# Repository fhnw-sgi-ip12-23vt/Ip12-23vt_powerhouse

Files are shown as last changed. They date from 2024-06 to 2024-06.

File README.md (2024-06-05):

# Powerhouse

## Readme
***
In diesem Readme werden auf alle wichtigen Elemente verwiesen.

## Überblick über das Projekt Powerhouse
***
Alle wichtigen Elemente der Software-Architektur, sowie alle Informationen zu verwendeter Hardware finden Sie in der Dokumentation. Diese ist folgendermassen aufgeteilt:

* [Hardware-Dokumentation](https://github.com/fhnw-sgi-ip12-23vt/Ip12-23vt_powerhouse/blob/f4988460a4c3d4b095565e1390c6c0ab0d1195cb/docu/hardware/Hardware.adoc)

* [Bedienungsanleitung Spiel](https://github.com/fhnw-sgi-ip12-23vt/Ip12-23vt_powerhouse/blob/d943952f26c9792b2c2e0c8939f13d876f54f816/docu/hardware/Bedienungsanleitung%20Spiel.adoc)

* [Softwaredokumentation (SAD)](https://github.com/fhnw-sgi-ip12-23vt/Ip12-23vt_powerhouse/blob/c4615cf55405ba9b3537b55cfcc192cdb2d660c0/docu/software(sad)/arc42-template.adoc)

* [Bedieungsanleitung Software](https://github.com/fhnw-sgi-ip12-23vt/Ip12-23vt_powerhouse/blob/d943952f26c9792b2c2e0c8939f13d876f54f816/docu/software(sad)/Bedienungsanleitung%20Software.adoc)

(überall Link einfügen)

In der **Hardwaredokumentation** sind alle Produkte aufgelistet, die für den Bau des Produktes nötig sind.

1. [Teileliste](https://github.com/fhnw-sgi-ip12-23vt/Ip12-23vt_powerhouse/blob/f4988460a4c3d4b095565e1390c6c0ab0d1195cb/docu/hardware/Hardware.adoc) mit allen Teilen und den Abmessungen
2. [3D-Druck-Dateien](https://github.com/fhnw-sgi-ip12-23vt/Ip12-23vt_powerhouse/blob/d943952f26c9792b2c2e0c8939f13d876f54f816/docu/hardware/3D-Objekte%20Dateien) mit einer Auflistung der Abmessungen 
3. [Kostenübersicht](https://github.com/fhnw-sgi-ip12-23vt/Ip12-23vt_powerhouse/blob/d943952f26c9792b2c2e0c8939f13d876f54f816/docu/hardware/Kosten%C3%BCbersicht.adoc)

#### Datenblätter
Die Datenblätter sind [hier](https://github.com/fhnw-sgi-ip12-23vt/Ip12-23vt_powerhouse/blob/d943952f26c9792b2c2e0c8939f13d876f54f816/docu/hardware/Datenbl%C3%A4tter) zu finden.

## Programmierkonventionen (Coding-Conventions)
***
Folgende Konventionen werden im Projekt Powerhouse eingehalten:
Namenskonventionen: Packagenamen sind immer klein,

* Klassen sind CamelCase, Variablen sind drinkingCamelCase, Konstanten und Enums sind in UPPER_CASE.
* 1 Tabulator/4 Leerschläge Einrückung pro Block.
* Keine Mehrfachdeklarationen pro Zeile.
* Öffnende Klammer auf der vorherigen Zeile, schliessende auf eine neue Zeile.
* Zeilen sind max. 120 Zeichen lang
* Verkettungen sind umgebrochen auf neue Zeilen mit 8 Leerzeichen Einrückung
* Klassengrösse: nicht grösser als 300 Zeilen

 Im Projekt Powerhouse wird eine [Checkstyle](https://checkstyle.sourceforge.io/) Konfiguration verwendet.

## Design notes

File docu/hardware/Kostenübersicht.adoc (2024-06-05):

_Hier stehen die Kostenübersicht._

[cols="1,1,1,1" options="header"]
|===
|Produkt |Beschreibung |Einkaufsort |Kosten in CHF
|Puppenhaus |FLISAT Puppenhaus |Ikea |19.95
|Holz |Sperrholz Pappel 8 mm dick |DO IT + GARDEN Migros |30.05
|Hobbyglas |Hobbyglas Transparent, 100 × 50 cm, 2 mm |Jumbo |11.95
|Kistengriffe |2 Stk. Kistengriff Verzinkt Buntchrom, 100 × 80 × 15 mm |Jumbo |9.60
|Scharniere |2 Stk. Ayce Scharnier Kantig Gelb Verzinkt, 50 × 50 mm |Jumbo |5.40
|Universalschrauben | Universalschraube, 3 × 20 mm |Migros |5.75
|Schrauben | Schrauben M 3 x 16 mm | Migros |1.95
|Schrauben | Schrauben M 4 x 16 mm | Migros |2.25
|Schrauben | Linsenschrauben M 4 x 16 mm | Migros |2.25
|Drucktaster | 20 Stk. Miniatur-Drucktaster | Reichelt | 12.61
|Wiederstand | 30 Stk. Wiederstand, Kohleschicht, 75 Ohm | Reichelt | 0.80
|LED | 20 Stk. LED, 5 mm, bedrahtet, grün, 39000 mcd, 15°| Reichelt | 4.33
|Steckbrückenkabel | 3 x 20 Stk., Stekcbrückenkabel, 50 cm | Reichelt | 19.19
|Bausatz i2C-Output | Bausatz i2C-Output | Horter & Kalb | 20.90
|Raspberry Pi 4 | Raspberry Pi 4 Model B 4 GB | Ali Cengiz | 53.30

|*Total* | | | *200.00*
|===

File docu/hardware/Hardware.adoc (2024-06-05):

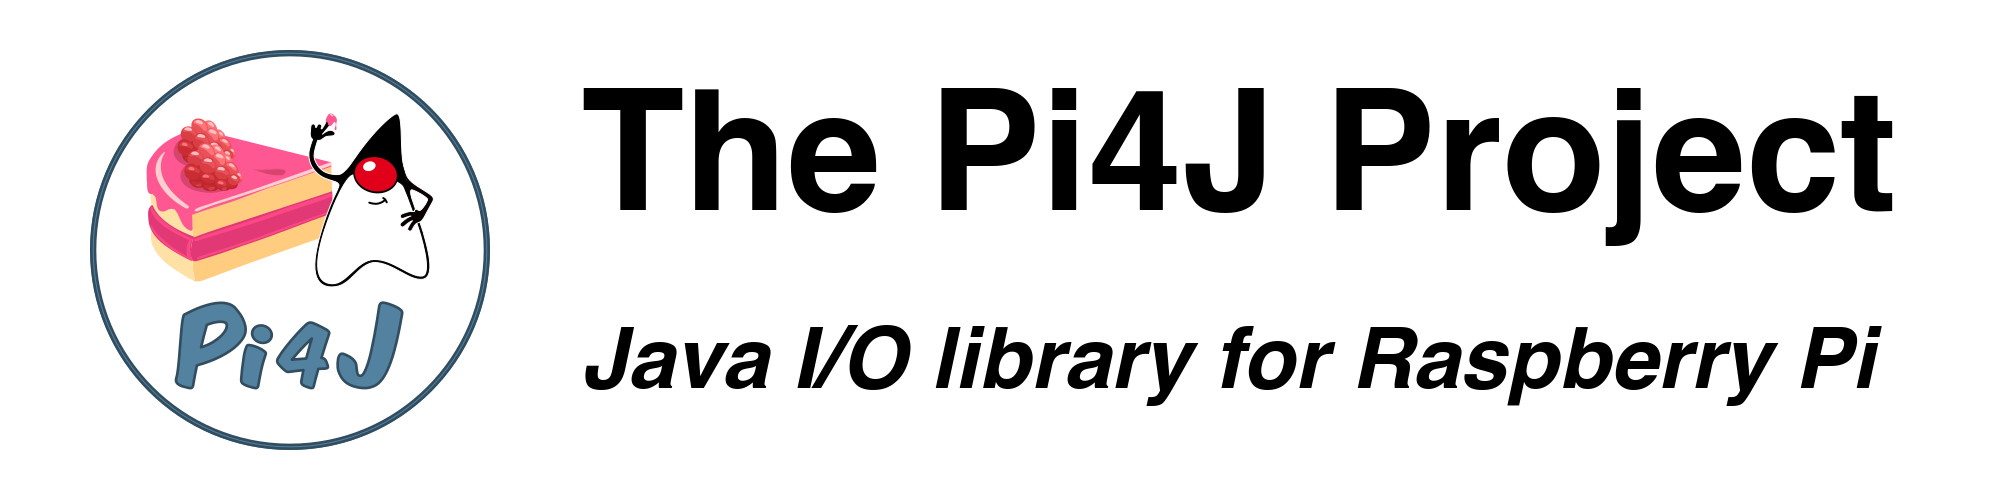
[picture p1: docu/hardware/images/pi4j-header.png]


_Hier stehen die Informationen zur Hardware._

Informationen zum Erstellen und Zusammenbauen finden sie hier: https://www.cs.technik.fhnw.ch/confluence20/display/IP1222vt/Material[]

*Teileliste Elektronik*
[cols="1,1,1,1" options="header"]
|===
|Produkt |Anzahl | Beschreibung |Einkaufsort
|Drucktaster|14 Stk.| Miniatur-Drucktaster|https://www.reichelt.com/ch/de/miniatur-drucktaster-0-5a-24vac-1x-ein-bl-t-250a-bl-p19983.html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[Reichelt]
|Wiederstand | 12 Stk.| Wiederstand | -
|LED | 12 Stk.| LED, 5 mm, bedrahtet, grün, 39000 mcd, 15°| https://www.reichelt.com/ch/de/led-5-mm-bedrahtet-gruen-39000-mcd-15--led-5-39000-gn-p163989.html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[Reichelt]
|Output Module | 2 Stk. | Kit I2C digital output Module| https://www.horter-shop.de/en/i2c-din-rail-modules/117-426-kit-i2c-digital-output-module-4260404260721.html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[Horter & Kalb]

|===
*Teileliste Haus*
[cols="1,1,1,1" options="header"]
|===
|Produkt |Anzahl | Beschreibung |Einkaufsort
|Puppenhaus | 1 Stk. | FLISAT Puppenhaus, wurde auf Ricardo ersteigert für den halben Preis |https://www.ikea.com/ch/en/p/flisat-doll-s-house-wall-shelf-50290785/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[Ikea]
|Holz |1 Stk.| Sperrholz Pappel 8 mm dick |https://www.doitgarden.ch/de/p/640138700000/sperrholz-pappel[DO IT + GARDEN Migros]
|Hobbyglas |1 Stk. | Hobbyglas Transparent, 100 × 50 cm, 2 mm |https://www.jumbo.ch/de/bauen-renovieren/bedachungsmaterialien/kunststoff-wellplatten/hobbyglas-transparent--100--50-cm--2-mm/p/6057452[Jumbo]
|Kistengriffe |2 Stk. | Kistengriff Verzinkt Buntchrom, 100 × 80 × 15 mm |https://www.jumbo.ch/de/maschinen-werkstatt/beschlaege-briefkaesten/beschlaege/ueberfallen-riegel/kistengriff-verzinkt-buntchrom--100--80--15-mm/p/3446281[Jumbo]
|Scharniere |2 Stk. | Scharnier, 100 × 50 mm | Migros
|Universalschrauben | 6 Stk. |  Universalschraube Senkkopf, M 4 × 16 mm, inkl. Mutter | https://www.doitgarden.ch/de/p/601537000000/suki-universalschraube-senkkopf-4x16mm[Migros]
|Universalschrauben | 8 Stk. | Universalschrauben Pan-Head M 4 × 16 mm, inkl. Mutter und Unterlagsscheibe | https://www.doitgarden.ch/de/p/601543200000/suki-universalschraube-pan-head-4x16mm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[Migros]
|Holzschrauben | 30 Stk. | Holzschrauben Linsenkopf verzinkt, 3 × 16 mm | -
|Klettverschluss | 2 Stk. | Klettverschluss selbstklebend, 18.5 x 1 cm| -
|Magnete | 7 Stk. | Magnete ⌀ 1 cm | -
|Blechscheiben | 7 Stk.| Blechscheiben ⌀ 2 cm | -

|===

*Abmessungen Holz für Schaltpult*
[cols="1,1,1" options="header"]
|===
|Teil |Länge |Breite
|Front für Knöpfe |58 cm |16 cm
|Front |58 cm | 4 cm
|Seite 2 Mal mit Abschrägung |44.4 cm |16 cm
|Deckel |58 cm |35 cm
|Boden |58 cm |46 cm
|Rückwand |58 cm |16 cm
|===
image::Schaltpult 1.png[]
image::Schaltpult 2.png[]
image::Schaltpult 3.png[]
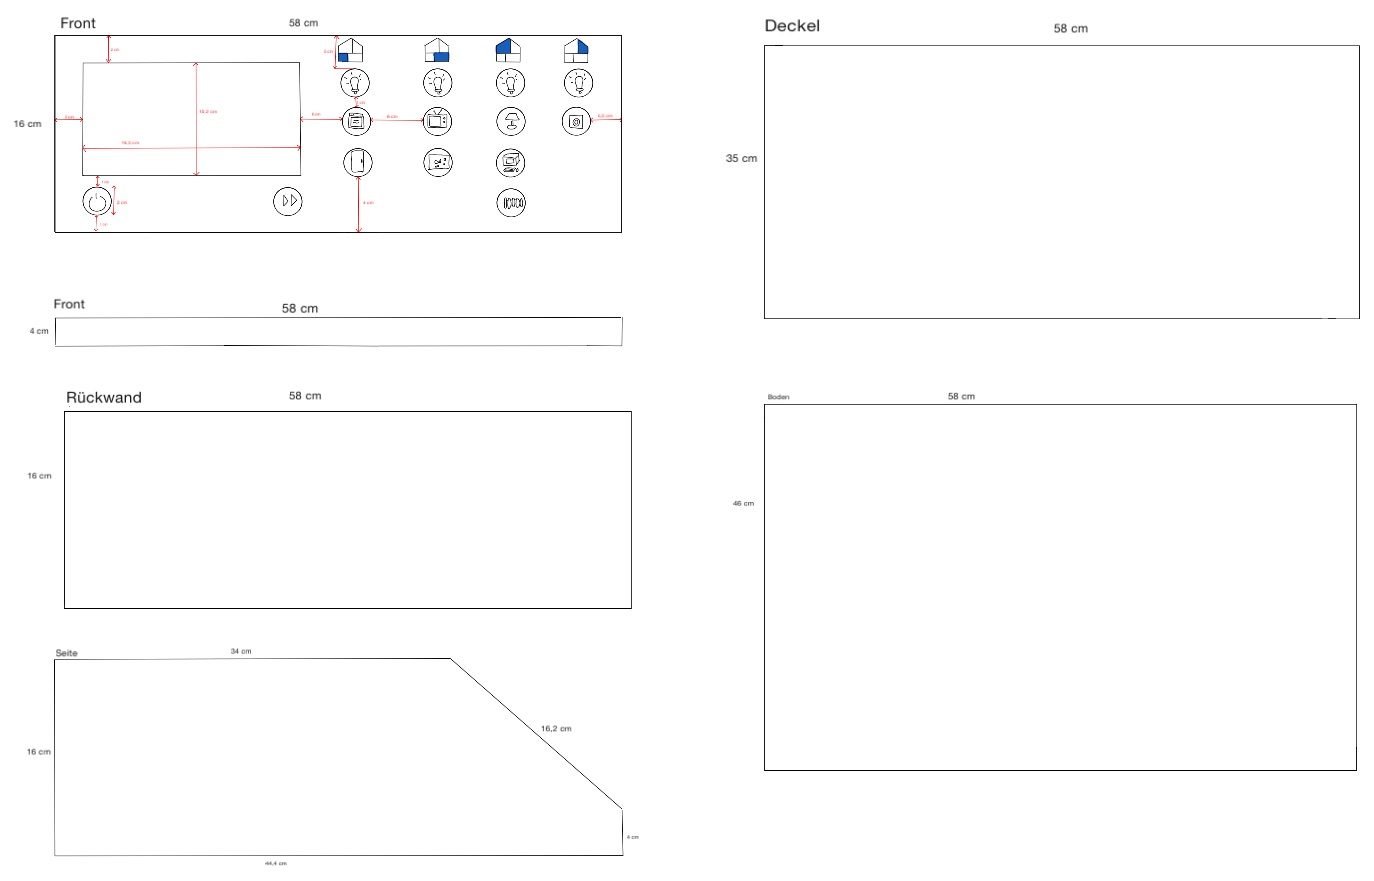
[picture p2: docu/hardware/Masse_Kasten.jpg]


*Abmessungen Plexiglas*
[cols="1,1,1,1" options="header"]
|===
|Produkt |Höhe |Breite |Tiefe
|Front | 50 cm| 58 cm| 0.2 cm
|Aquarium Glas gross  |7 cm |2.5 cm |0.2 cm
|Aquarium Glas klein 2x  |2.5 cm |2.5 cm |0.2 cm
|Dusche | 10 cm |5 cm| 0.2 cm
|Dusche | 10 cm |2.5 cm| 0.2 cm
|Abdeckung Bildschirm | 18.5 cm | 13.5 cm | 0.2 cm
|===

*Abmessungen 3D-Druck Küche*
[cols="1,1,1,1,1" options="header"]
|===
|Produkt |Höhe z |Breite x|Tiefe y|Farbe
|Lampe|15,51 mm | 33,82 mm| 33,82 mm| a
|Herd/Backofen |51,76 mm |45 mm| 29,5 mm| transparent
|Kühlschrank|102,12 | 45 mm |39,02 mm| transparent
|Essisch|44,99 mm | 90 mm| 50,47 mm| weiss
|2x Stühle|69,86 mm |34 mm| 37,57 mm| weiss
|Küchenschrank|48 mm | 45 mm| 20 mm| weiss
|Küchenschranktüre| 44,67 mm | 36,66mm| 4 mm| weiss
|Waschbecken|51,76 mm  |40,69 mm |29,71 mm | weiss
|Dunstabzugshaube| 54 mm| 45 mm| 39,54 mm| schwarz
|===

*Abmessungen 3D-Druck Wohnzimmer*
[cols="1,1,1,1,1" options="header"]
|===
|Produkt |Höhe z |Breite x|Tiefe y|Farbe
|Lampe|15,51 mm | 33,82 mm| 33,82 mm| schwarz
|Fernseher|29,63 mm | 37 mm| 39,21 mm| transparent
|Aquarium Tisch| 27,84 mm| 75 mm| 27,84 mm| schwarz
|Aquarium Deckel| 3,8 mm| 75 mm| 27,84 mm| schwarz
|Aquarium Rahmen| 26,05 mm| 75 mm| 27,84 mm| schwarz
|Musikanlage|15,32 mm | 45 mm| 30,84 mm| transparent
|Sofa|45,6 mm | 90 mm| 61 mm| blau
|Fernsehtisch |33 mm | 75 mm| 40 mm| weisse Oberfläche, schwarze Beine
|Spielkonsole| 27,5 mm | 22,5 mm | 23,75 mm| aussen weiss, innen schwarz
|2x Vase| 20 mm | 12,48 mm | 12,48 mm| weiss
|===

*Abmessungen 3D-Druck Schlafzimmer*
[cols="1,1,1,1,1" options="header"]
|===
|Produkt |Höhe |Breite |Tiefe|Farbe
|Lampe|15,51 mm | 33,82 mm| 33,82 mm| transparent
|Computer|40,83 mm | 38 mm| 31 mm| transparent
|Heizung|49 mm | 11,2 mm| 70 mm| transparent
|Nachttisch|33 mm |40 mm| 30 mm| weinrot/braun
|Bürotisch|61,1 mm |90 mm |53,73 mm| weiss
|Bürostuhl|111,82 mm |50 mm| 48,89 mm| blau
|Nachttischlampe|46,77 mm | 30 mm| 30 mm| transparent
|Bett | 60 mm| 70 mm| 120 mm | weiss
|Kleiderschrank | 135 mm | 35 mm | 75 mm | weinrot/braun
|Bücherregal | 136,08 mm | 35 mm | 19,84 mm | weinrot/braun
|===

*Abmessungen 3D-Druck Badezimmer*
[cols="1,1,1,1,1" options="header"]
|===
|Produkt |Höhe |Breite |Tiefe|Farbe
|Lampe|15,51 mm | 33,82 mm| 33,82 mm| a
|Waschmaschine/Tumbler|48,91 mm | 45 mm| 50,66 mm| transparent
|WC| 61,92 mm| 45 mm| 27,13 mm| weiss
|Waschbecken|71,13 mm |45 mm| 30,06 mm| weiss
|Duschkopf |7,69 mm |9,62 mm| 20 mm| weiss
|===

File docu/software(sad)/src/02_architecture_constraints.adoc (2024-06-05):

[[section-architecture-constraints]]
== Randbedingungen

[role="arc42help"]
****
.Inhalt
Randbedingungen und Vorgaben, die ihre Freiheiten bezüglich Entwurf, Implementierung oder Ihres Entwicklungsprozesses einschränken.
Diese Randbedingungen gelten manchmal organisations- oder firmenweit über die Grenzen einzelner Systeme hinweg.

.Motivation
Für eine tragfähige Architektur sollten Sie genau wissen, wo Ihre Freiheitsgrade bezüglich der Entwurfsentscheidungen liegen und wo Sie Randbedingungen beachten müssen.
Sie können Randbedingungen vielleicht noch verhandeln, zunächst sind sie aber da.

.Form
Einfache Tabellen der Randbedingungen mit Erläuterungen.
Bei Bedarf unterscheiden Sie technische, organisatorische und politische Randbedingungen oder übergreifende Konventionen (beispielsweise Programmier- oder Versionierungsrichtlinien, Dokumentations- oder Namenskonvention).

.Weiterführende Informationen

Siehe https://docs.arc42.org/section-2/[Randbedingungen] in der online-Dokumentation (auf Englisch!).

****

=== Technische Randbedingungen

[cols="3,3" options="header"]
|===
|Randbedingung |Erläuterung
| Hardware | Das System soll auf einem Raspberry Pi 4 laufen.
| Implementierung in Java |Im Rahmen der Projektschiene wird Java verwendet.
|===

=== Organisatorische Randbedingungen

[cols="3,5" options="header"]
|===
|Randbedingung |Erläuterung
| Team | Unser Projektteam, unterstützt durch Teamcoach.
| Budget | Das Budget für das Projekt beträgt 200 CHF.
| Zeitplan | Beginn des Projektes August 2023, Ende im August 2024, Zeitbudget: 180 Stunden pro Person pro Semester.
| Vorgehensmodell | Im Projekt wird mit dem RUP Modell gearbeitet.
| Versionsverwaltung | Versionsverwaltung mit Git auf Gitlab.
|===

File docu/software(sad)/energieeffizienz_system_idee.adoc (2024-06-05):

= Systemidee
Gruppe 2: Energieeffizienz
:toc:

== Kernaufgabe des Systems
Die Kernaufgabe des Systems ist die Darstellung von Energieeffizienz im Alltag. Das System ist verantwortlich für ein flüssiges und stabiles Spielerlebnis.

Wichtige Begriffe beziehen sich auf das Projekt, was muss jemand wissen um das Projekt zu verstehen.

- *Energieeffizienz*: Im System bezieht sich Energieeffizienz auf das Sparen von Energie

== Kategorie von System
Das System ist ein eingebettetes System mit Echtzeitanforderungen. Das System arbeitet eng mit einem Raspberry Pi zusammen. Die Echtzeitanforderungen beziehen sich auf eine schnelle Aufnahme von User Inputs.

== Wesentliche Qualitätsanforderungen
* *Änderbarkeit*:
** Das Spiel soll über eine Datei konfigurierbar sein, damit es schnell angepasst werden kann
* *Effizienz*:
** Das Spiel soll eine schnelle Antwortzeit haben
* *Übertragbarkeit*:
** Das Spiel soll ohne Internet verwendbar sein
** Das Spiel soll gut transportierbar sein
** Das System soll mit einem Autostart ausgestattet sein
* *Zuverlässigkeit*:
** Das Spiel wird von bis zu 20'000 Besucher*innen benutzt
* *Funktionalität*:
** Erfüllen der festgelegten Features
* *Benutzbarkeit*:
** Das Spiel soll selbsterklärend oder in 30 Sekunden erklärbar sein
** Das Spiel soll für Jugendliche ansprechend gestaltet sein

== Relevante Stakeholder
- Primeo Energie: Betreiber und Administrator des Systems
- FHNW
- Yves Simmen: Auftraggeber
- Fachcoaches
- Projekt Team
- Benutzer*innen: Besucher des Energiekosmoses
- Lehrpersonen

== Schnittstellen zu externen Systemen
- Keine

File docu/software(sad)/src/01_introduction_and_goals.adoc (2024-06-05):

[[section-introduction-and-goals]]
==	Einführung und Ziele

[role="arc42help"]
****
Beschreibt die wesentlichen Anforderungen und treibenden Kräfte, die bei der Umsetzung der Softwarearchitektur und Entwicklung des Systems berücksichtigt werden müssen.

Dazu gehören:

* zugrunde liegende Geschäftsziele,
* wesentliche Aufgabenstellungen,
* wesentliche funktionale Anforderungen,
* Qualitätsziele für die Architektur und
* relevante Stakeholder und deren Erwartungshaltung.
****

=== Aufgabenstellung

[role="arc42help"]
****
.Inhalt
Kurzbeschreibung der fachlichen Aufgabenstellung, treibenden Kräfte, Extrakt (oder Abstract) der Anforderungen.
Verweis auf (hoffentlich vorliegende) Anforderungsdokumente (mit Versionsbezeichnungen und Ablageorten).

.Motivation
Aus Sicht der späteren Nutzung ist die Unterstützung einer fachlichen Aufgabe oder Verbesserung der Qualität der eigentliche Beweggrund, ein neues System zu schaffen oder ein bestehendes zu modifizieren.

.Form
Kurze textuelle Beschreibung, eventuell in tabellarischer Use-Case Form.
Sofern vorhanden, sollte die Aufgabenstellung Verweise auf die entsprechenden Anforderungsdokumente enthalten.

Halten Sie diese Auszüge so knapp wie möglich und wägen Sie Lesbarkeit und Redundanzfreiheit gegeneinander ab.

.Weiterführende Informationen

Siehe https://docs.arc42.org/section-1/[Anforderungen und Ziele] in der online-Dokumentation (auf Englisch!).

****

===== Was ist Powerhouse?

* Powerhouse ist ein Puzzle Spiel.
* Das Ziel ist es Jugendlichen das Thema Energieeffizienz näherzubringen.
* Die Spieler*innen müssen in einem Puppenhaus Energie sparen.

===== Wichtige Features:

* Spieler interagieren mit dem Puppenhaus und steuern verschiedene Alltagsgegenstände.
* Der Energieverbrauch von Alltagsgegenständen wird realistisch simuliert.

=== Qualitätsziele

[role="arc42help"]
****
.Inhalt
Die Top-3 bis Top-5 der Qualitätsanforderungen für die Architektur, deren Erfüllung oder Einhaltung den maßgeblichen Stakeholdern besonders wichtig sind.
Gemeint sind hier wirklich Qualitätsziele, die nicht unbedingt mit den Zielen des Projekts übereinstimmen. 
Beachten Sie den Unterschied.

Hier ein Überblick möglicher Themen (basierend auf dem ISO 25010 Standard):

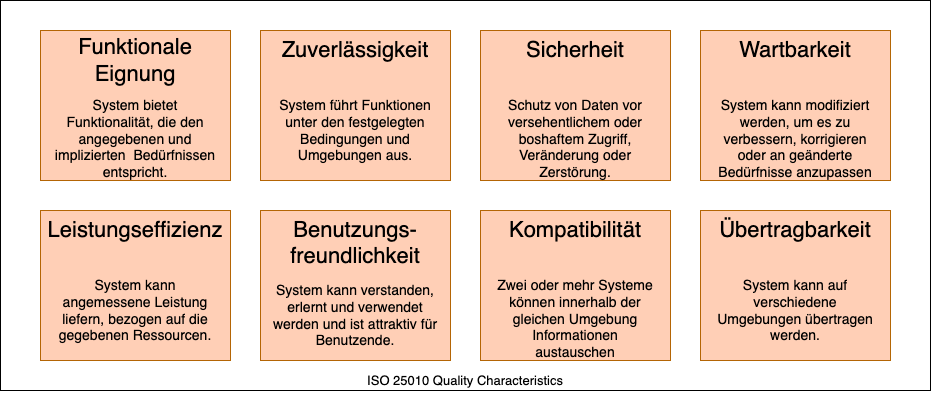
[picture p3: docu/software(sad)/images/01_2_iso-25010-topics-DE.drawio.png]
Kategorien von Qualitätsanforderungen


.Motivation
Weil Qualitätsziele grundlegende Architekturentscheidungen oft maßgeblich beeinflussen, sollten Sie die für Ihre Stakeholder relevanten Qualitätsziele kennen, möglichst konkret und operationalisierbar.

.Form
Tabellarische Darstellung der Qualitätsziele mit möglichst konkreten Szenarien, geordnet nach Prioritäten.
****

Die folgende Tabelle zeigt die wichtigsten Qualitätsziele.
[cols="1,1" options="header"]
|===
|Kategorie |Beschreibung
| Effizienz | Das Spiel soll eine schnelle Antwortzeit haben
| Zuverlässigkeit |Das Spiel wird von bis zu 20'000 Besucher*innen benutzt
| Änderbarkeit | Das Spiel soll über eine Datei konfigurierbar sein, damit es schnell angepasst werden kann
|===

=== Stakeholder

[role="arc42help"]
****
.Inhalt
Expliziter Überblick über die Stakeholder des Systems – über alle Personen, Rollen oder Organisationen –, die

* die Architektur kennen sollten oder
* von der Architektur überzeugt werden müssen,
* mit der Architektur oder dem Code arbeiten (z.B. Schnittstellen nutzen),
* die Dokumentation der Architektur für ihre eigene Arbeit benötigen,
* Entscheidungen über das System und dessen Entwicklung treffen.

.Motivation
Sie sollten die Projektbeteiligten und -betroffenen kennen, sonst erleben Sie später im Entwicklungsprozess Überraschungen.
Diese Stakeholder bestimmen unter anderem Umfang und Detaillierungsgrad der von Ihnen zu leistenden Arbeit und Ergebnisse.

.Form
Tabelle mit Rollen- oder Personennamen, sowie deren Erwartungshaltung bezüglich der Architektur und deren Dokumentation.
****

In Folgendem werden die Stakeholder und ihre Erwartungen beschrieben.
[cols="1,1,2" options="header"]
|===
|Rolle |Kontakt |Erwartungshaltung
| Betreiber und Administrator des Systems | Primeo Energie | Lehrreiches Spiel über Energiesparen für Jugendliche
| Auftraggeber | Yves Simmen | Gute, konstruktive Zusammenarbeit
| Benutzer*innen | Besucher des Energieskosmoses | Flüssiges und unterhaltsames Spielerlebnis
| Projekt Team | Projekt Team | Effizientes Ressourcenmanagement
| FHNW | Louis Paul Wicki | Studierende können ihr Wissen praktisch anwenden
|===

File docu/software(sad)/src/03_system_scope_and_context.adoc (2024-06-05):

[[section-system-scope-and-context]]
== Kontextabgrenzung

[role="arc42help"]
****
.Inhalt
Die Kontextabgrenzung grenzt das System gegen alle Kommunikationspartner (Nachbarsysteme und Benutzerrollen) ab.
Sie legt damit die externen Schnittstellen fest und zeigt damit auch die Verantwortlichkeit (scope) Ihres Systems: Welche Verantwortung trägt das System und welche Verantwortung übernehmen die Nachbarsysteme?

Differenzieren Sie fachlichen (Ein- und Ausgaben) und technischen Kontext (Kanäle, Protokolle, Hardware), falls nötig.

.Motivation
Die fachlichen und technischen Schnittstellen zur Kommunikation gehören zu den kritischsten Aspekten eines Systems.
Stellen Sie sicher, dass Sie diese komplett verstanden haben.

.Form
Verschiedene Optionen:

* Diverse Kontextdiagramme
* Listen von Kommunikationsbeziehungen mit deren Schnittstellen

.Weiterführende Informationen

Siehe https://docs.arc42.org/section-3/[Kontextabgrenzung] in der online-Dokumentation (auf Englisch!).

****

=== Fachlicher Kontext

[role="arc42help"]
****
.Inhalt
Festlegung *aller* Kommunikationsbeziehungen (Nutzer, IT-Systeme, ...) mit Erklärung der fachlichen Ein- und Ausgabedaten oder Schnittstellen.
Zusätzlich (bei Bedarf) fachliche Datenformate oder Protokolle der Kommunikation mit den Nachbarsystemen.

.Motivation
Alle Beteiligten müssen verstehen, welche fachlichen Informationen mit der Umwelt ausgetauscht werden.

.Form
Alle Diagrammarten, die das System als Blackbox darstellen und die fachlichen Schnittstellen zu den Nachbarsystemen beschreiben.

Alternativ oder ergänzend können Sie eine Tabelle verwenden.
Der Titel gibt den Namen Ihres Systems wieder; die drei Spalten sind: Kommunikationsbeziehung, Eingabe, Ausgabe.
****

**<Diagramm und/oder Tabelle>**

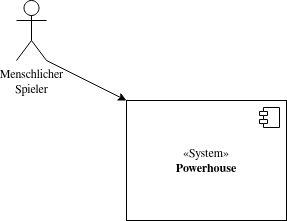
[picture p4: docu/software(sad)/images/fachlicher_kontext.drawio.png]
Bild: Fachlicher Kontext von Powerhouse


**<optional: Erläuterung der externen fachlichen Schnittstellen>**

==== Menschlicher Spieler (Benutzer)

Powerhouse wird von einem Spieler gespielt. Powerhouse leitet den Spieler durch das Spiel. Dabei nimmt das System die Antworten und Entscheidungen des Spielers entgegen.

==== Fremdsysteme

Das System kommuniziert mit keinen Fremdsystemen. (Eventuell Build System?)

=== Technischer Kontext

[role="arc42help"]
****
.Inhalt
Technische Schnittstellen (Kanäle, Übertragungsmedien) zwischen dem System und seiner Umwelt.
Zusätzlich eine Erklärung (_mapping_), welche fachlichen Ein- und Ausgaben über welche technischen Kanäle fließen.

.Motivation
Viele Stakeholder treffen Architekturentscheidungen auf Basis der technischen Schnittstellen des Systems zu seinem Kontext.

Insbesondere bei der Entwicklung von Infrastruktur oder Hardware sind diese technischen Schnittstellen durchaus entscheidend.

.Form
Beispielsweise UML Deployment-Diagramme mit den Kanälen zu Nachbarsystemen, begleitet von einer Tabelle, die Kanäle auf Ein-/Ausgaben abbildet.
****

**<Diagramm oder Tabelle>**

**<optional: Erläuterung der externen technischen Schnittstellen>**

**<Mapping fachliche auf technische Schnittstellen>**

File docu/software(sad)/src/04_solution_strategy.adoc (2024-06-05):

[[section-solution-strategy]]
== Lösungsstrategie

[role="arc42help"]
****
.Inhalt
Kurzer Überblick über die grundlegenden Entscheidungen und Lösungsansätze, die Entwurf und Implementierung des Systems prägen.
Hierzu gehören:

* Technologieentscheidungen
* Entscheidungen über die Top-Level-Zerlegung des Systems, beispielsweise die Verwendung gesamthaft prägender Entwurfs- oder Architekturmuster,
* Entscheidungen zur Erreichung der wichtigsten Qualitätsanforderungen sowie
* relevante organisatorische Entscheidungen, beispielsweise für bestimmte Entwicklungsprozesse oder Delegation bestimmter Aufgaben an andere Stakeholder.

.Motivation
Diese wichtigen Entscheidungen bilden wesentliche „Eckpfeiler“ der Architektur.
Von ihnen hängen viele weitere Entscheidungen oder Implementierungsregeln ab.

.Form
Fassen Sie die zentralen Entwurfsentscheidungen *kurz* zusammen.
Motivieren Sie, ausgehend von Aufgabenstellung, Qualitätszielen und Randbedingungen, was Sie entschieden haben und warum Sie so entschieden haben.
Vermeiden Sie redundante Beschreibungen und verweisen Sie eher auf weitere Ausführungen in Folgeabschnitten.

.Weiterführende Informationen

Siehe https://docs.arc42.org/section-4/[Lösungsstrategie] in der online-Dokumentation (auf Englisch!).

****

[cols="1,1" options="header"]
|===
|Qualitätsziel |Ansätze in der Architektur
| Effizienz | Keine Datenbank, keine Wiederholungen
| Zuverlässigkeit | MVC-Modell
| Änderbarkeit | Konfiguration mittels .ini File

|===

=== Aufbau

Powerhouse ist ein Java-Programm und nach dem MVC-Modell aufgebaut. Es ist unterteilt in:

* Model Klassen -> Speichern Zustände.
* View Klassen -> Darstellung der Zustände, überwacht Zustände von Model Klassen.
* Controller Klassen -> Logik und Kommunikation mit dem Modell.
* Starter Klasse -> Startet das Programm.

Diese Abstrahierung macht das System übersichtlich und erlaubt verschiedene Ansätze für den Input und die Darstellung von Daten.

=== JavaFX
Im System wird JavaFX für alle GUI Elemente verwendet.

JavaFX ist weit verbreitet und ist gut dokumentiert. Zusätzlich ist die Implementierung von verschiedenen Scenes mittels JavaFX sehr nützlich.

=== Keine Datenbank für die Levels
Als Team haben wir uns entschieden keine externe Datenbank für die Aufgaben und Levels zu nutzten.

Gründe:

* Eine Datenbank würde die Performance vom Raspberry Pi einschränken.
* Die Levels kommen immer in der gleichen Reihenfolge und erfordern keine komplexen Abfragen.
* Würde System unnötig komplexer machen.

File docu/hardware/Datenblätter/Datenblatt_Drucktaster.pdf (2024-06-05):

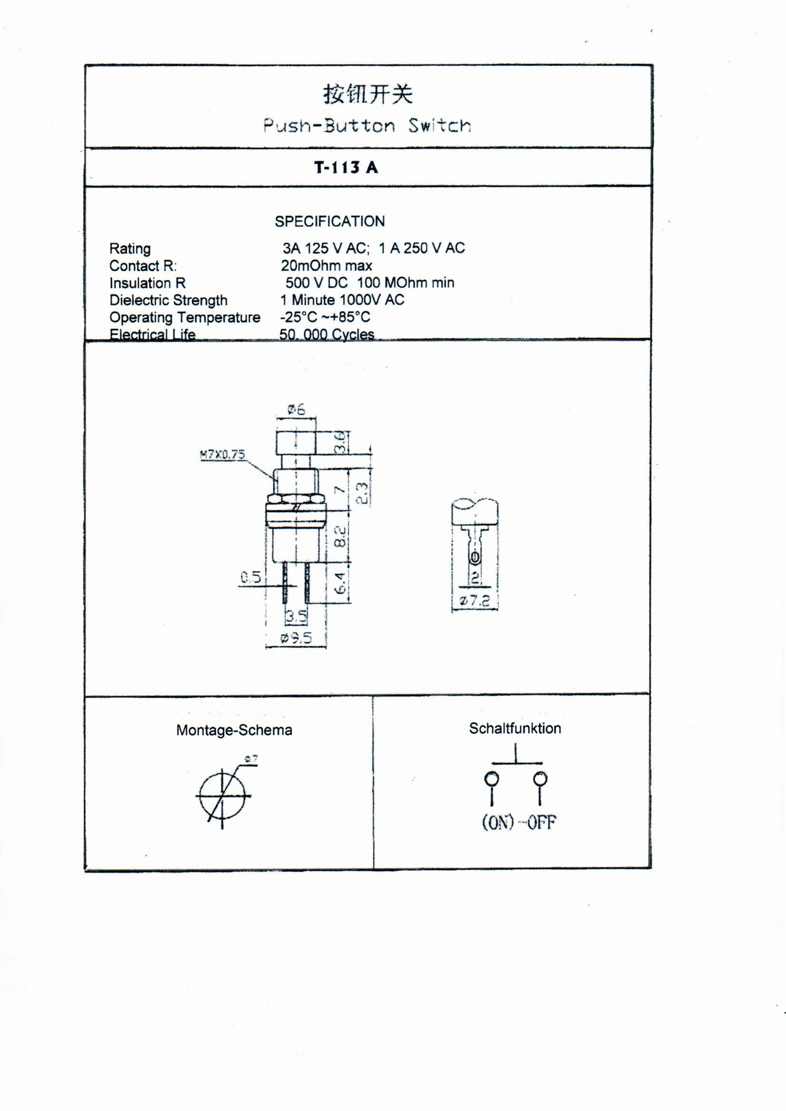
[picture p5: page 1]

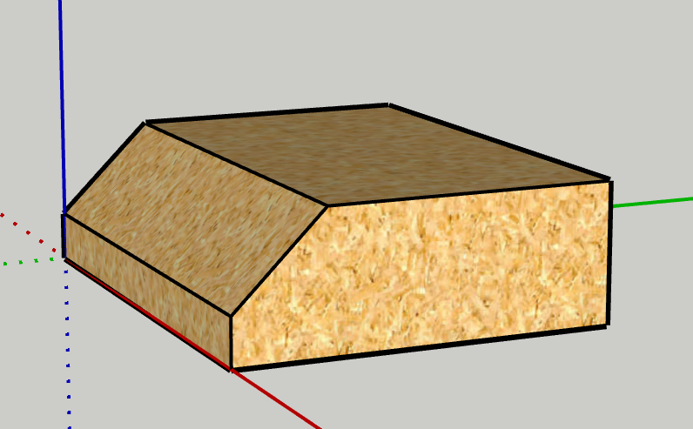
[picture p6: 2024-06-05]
docu/hardware/images/Schaltpult 3.png

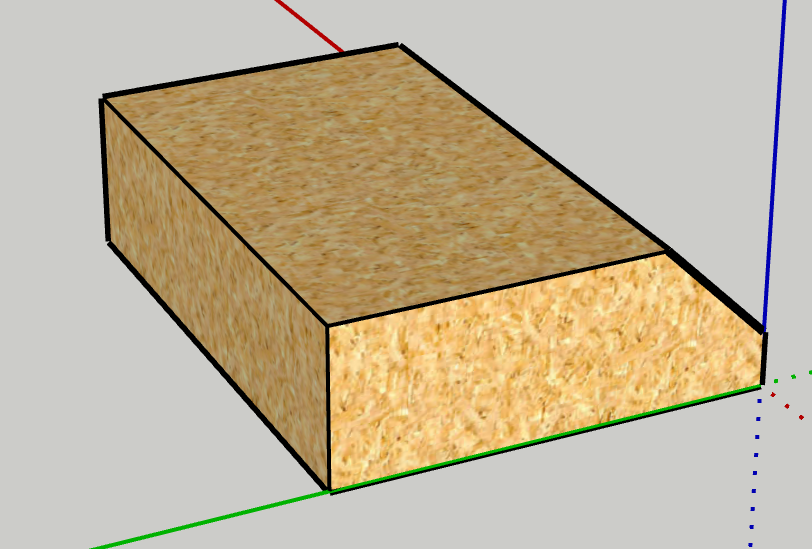
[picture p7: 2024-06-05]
docu/hardware/images/Schaltpult 1.png

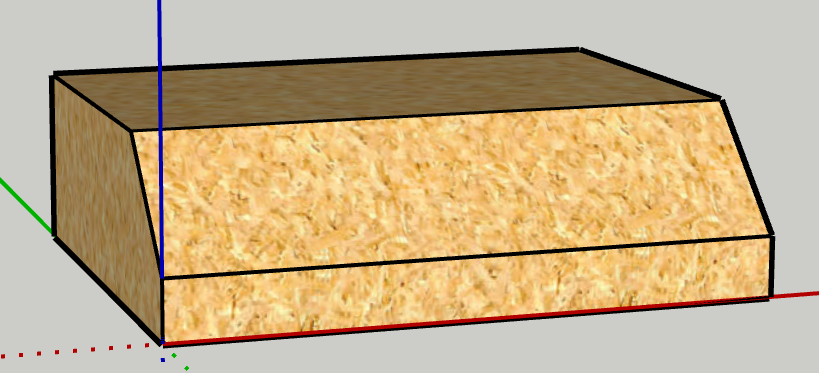
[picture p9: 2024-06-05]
docu/hardware/images/Schaltpult 2.png

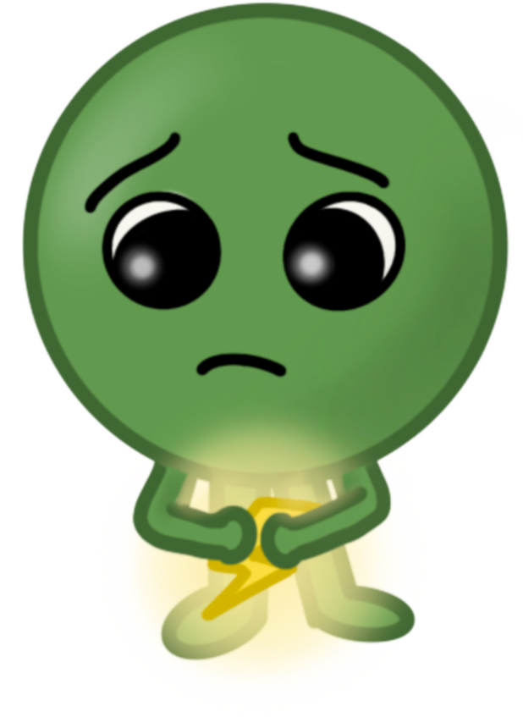
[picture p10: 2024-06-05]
energieeffizienz-sourcecode/src/main/resources/img/Elektronix/Level_8_Spielabbruch.png

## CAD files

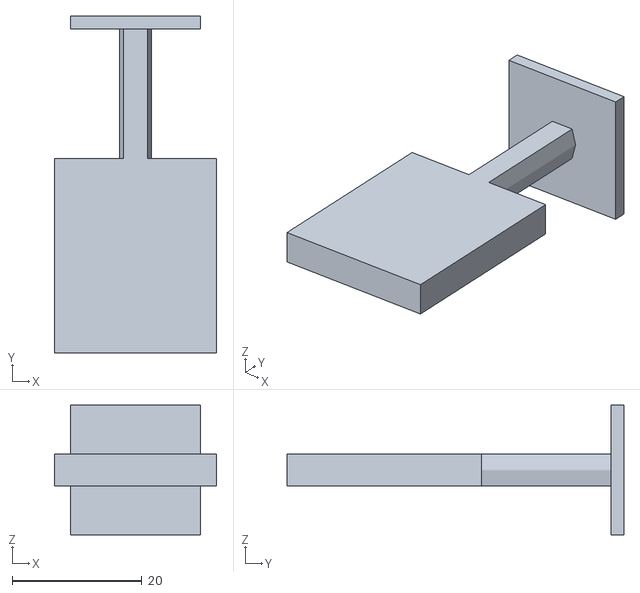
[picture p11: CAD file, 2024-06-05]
docu/hardware/3D-Objekte Dateien/Buttons/Duschkopf.stl
25.0 x 52.0 x 20.0

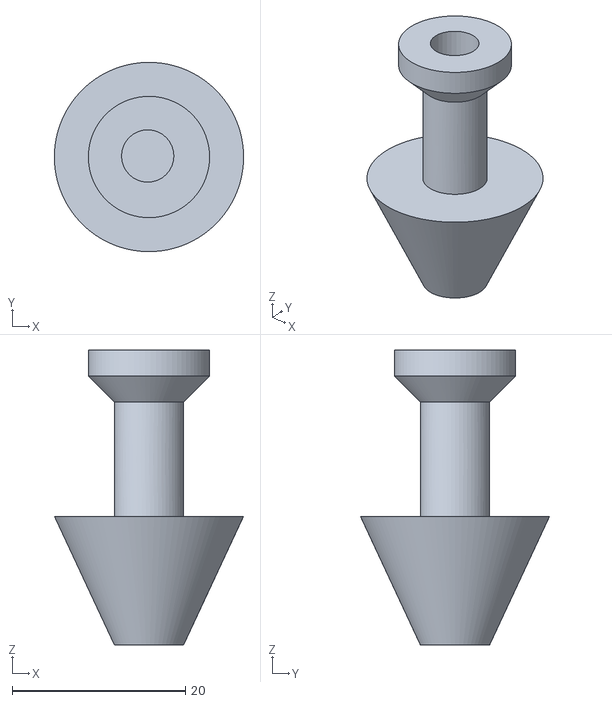
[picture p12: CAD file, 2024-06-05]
docu/hardware/3D-Objekte Dateien/Transparente Objekte/Nachttischlampe.stl
21.8 x 21.8 x 34.1

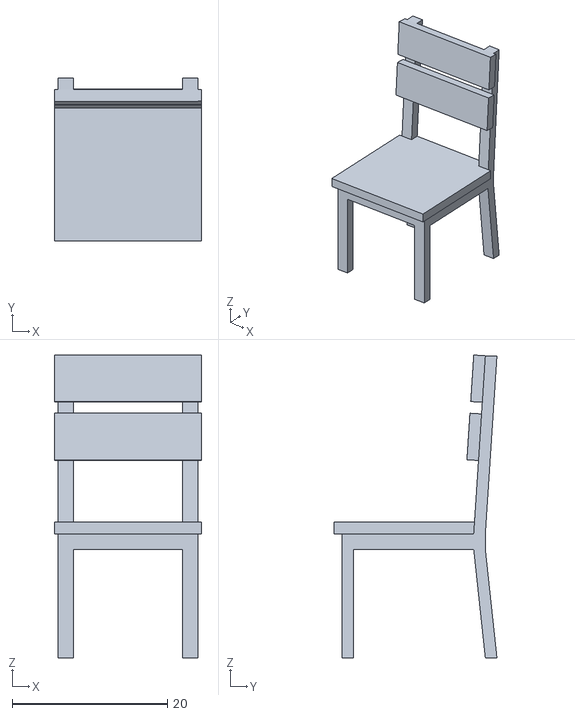
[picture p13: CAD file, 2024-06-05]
docu/hardware/3D-Objekte Dateien/Weitere Objekte/Küche/Küchenstuhl.stl
19.0 x 21.0 x 39.0

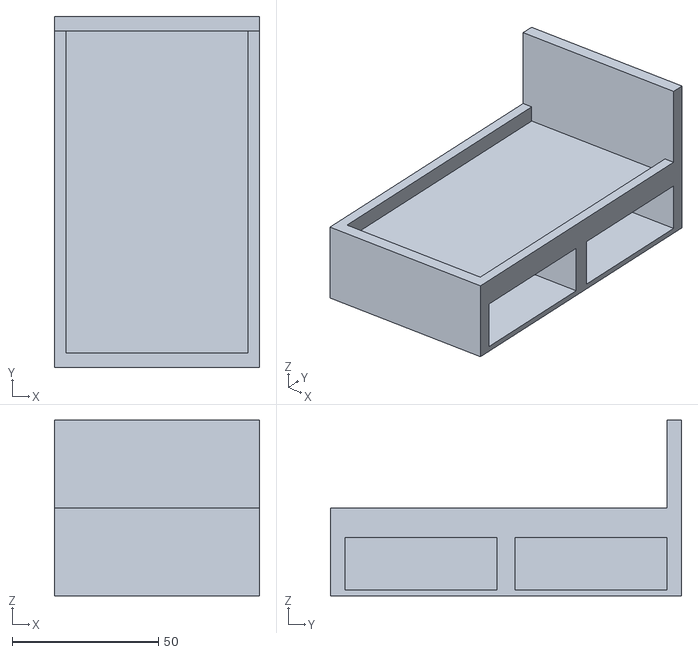
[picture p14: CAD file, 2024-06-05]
docu/hardware/3D-Objekte Dateien/Weitere Objekte/Schlafzimmer/Bett.stl
70.0 x 120.0 x 60.0

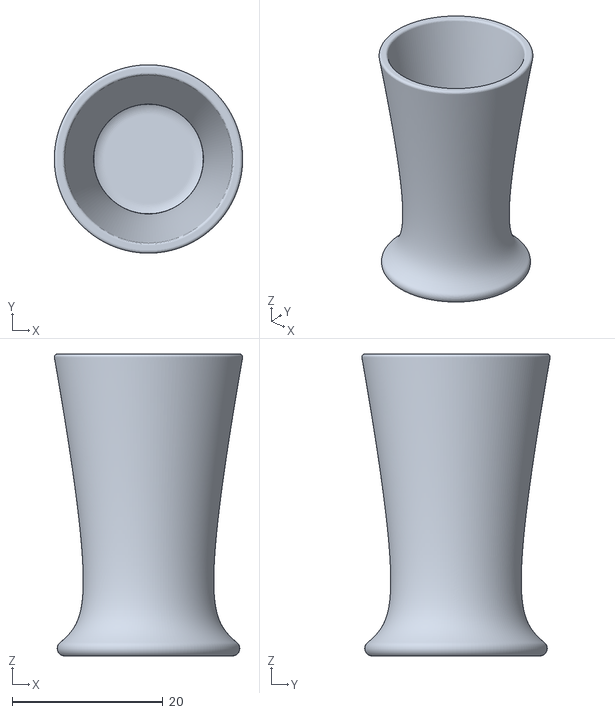
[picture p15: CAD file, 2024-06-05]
docu/hardware/3D-Objekte Dateien/Weitere Objekte/Wohnzimmer/Vase.stl
25.0 x 25.0 x 40.0

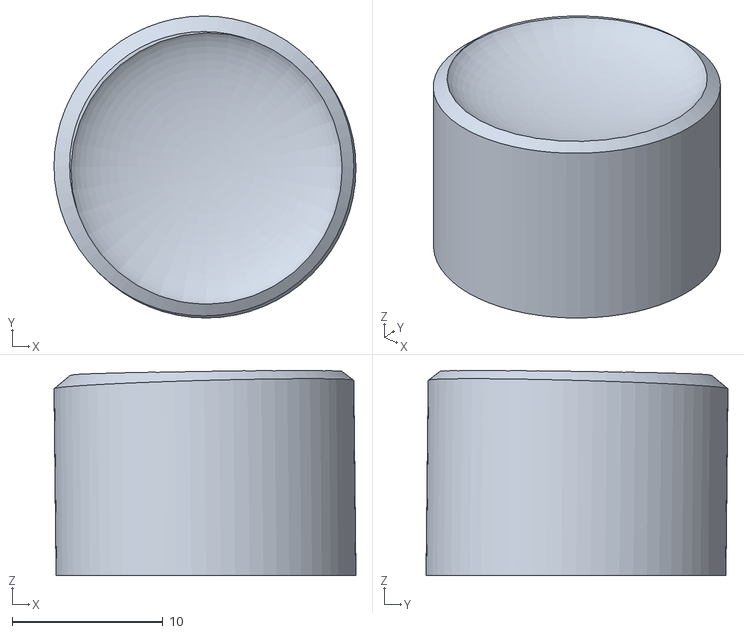
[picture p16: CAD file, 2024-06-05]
docu/hardware/3D-Objekte Dateien/Buttons/Button Blank.stl
20.0 x 20.0 x 13.6

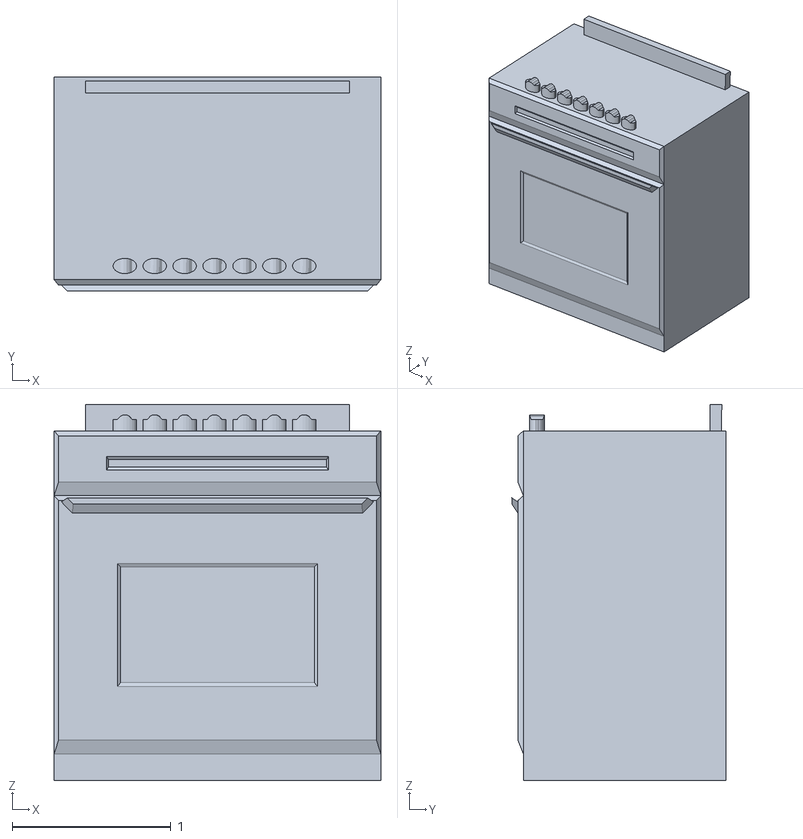
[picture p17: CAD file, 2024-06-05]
docu/hardware/3D-Objekte Dateien/Transparente Objekte/Backofen_Herd.stl
2.06 x 1.35 x 2.37

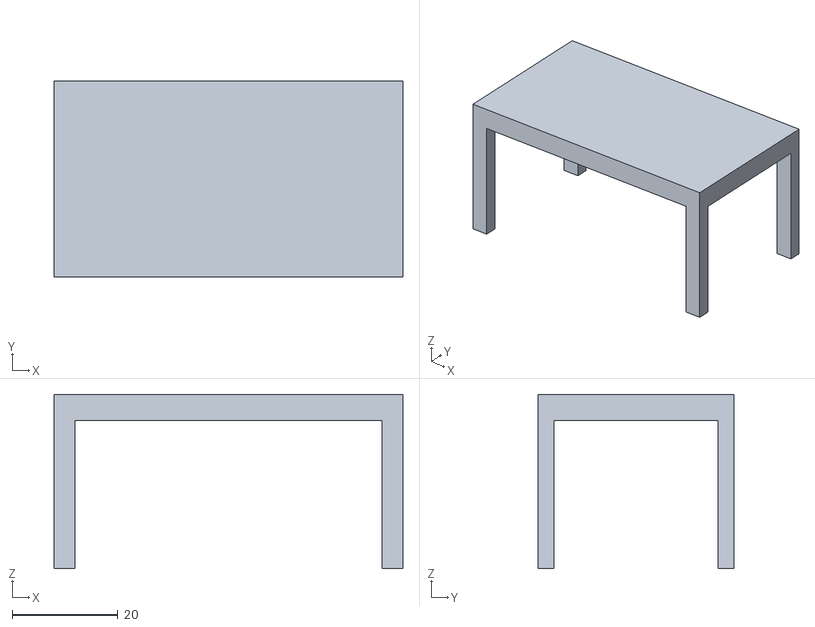
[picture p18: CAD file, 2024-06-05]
docu/hardware/3D-Objekte Dateien/Weitere Objekte/Küche/Esstisch.stl
66.0 x 37.0 x 33.0

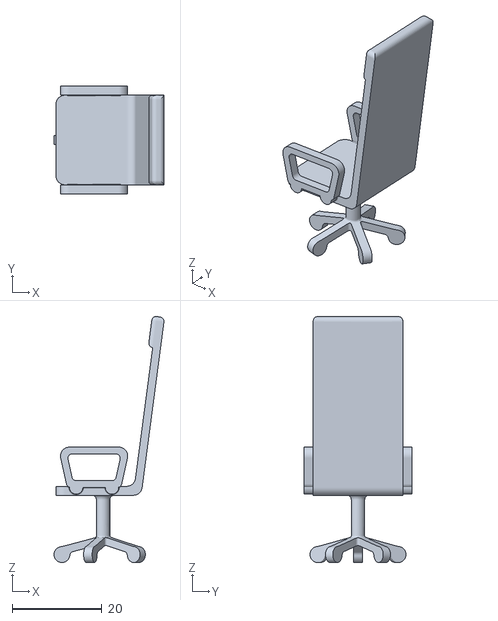
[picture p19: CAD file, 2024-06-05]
docu/hardware/3D-Objekte Dateien/Weitere Objekte/Schlafzimmer/Bürostuhl.stl
24.5 x 24.0 x 54.9

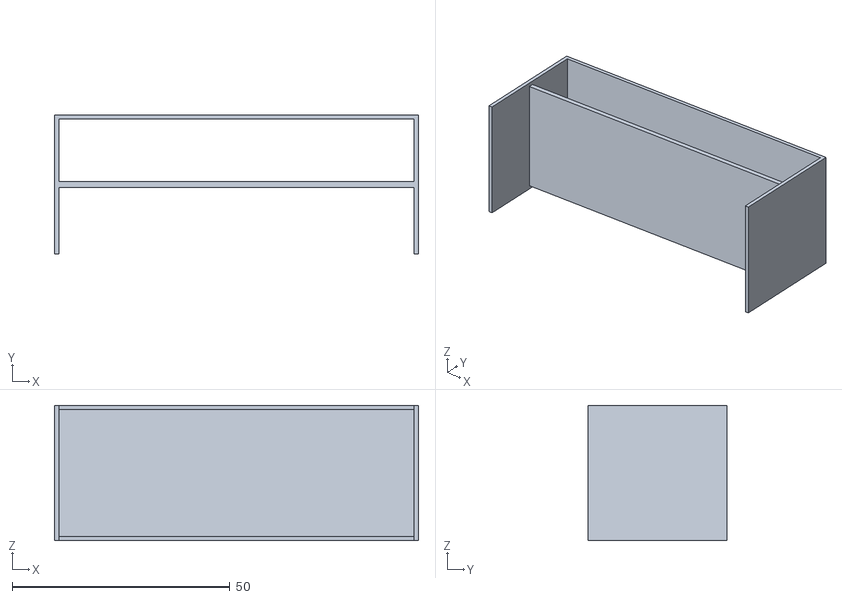
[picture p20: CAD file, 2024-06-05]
docu/hardware/3D-Objekte Dateien/Weitere Objekte/Wohnzimmer/Aquarium_Tisch.stl
83.5 x 32.0 x 31.0

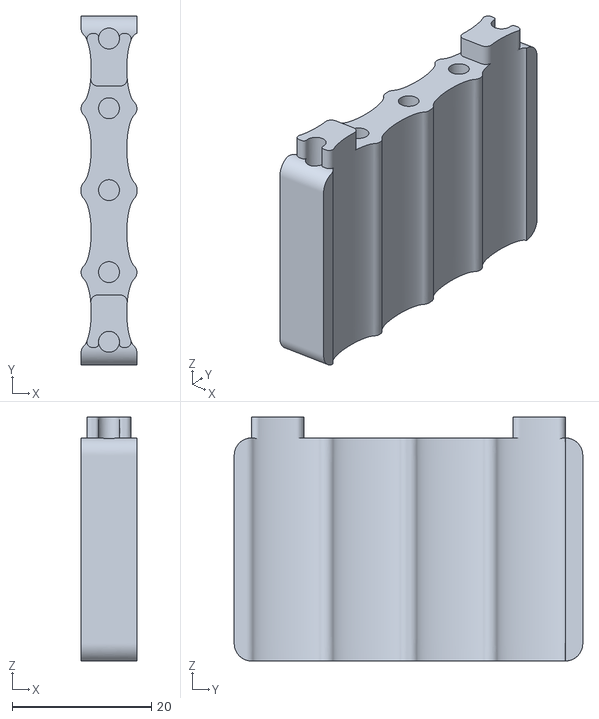
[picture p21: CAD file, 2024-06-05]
docu/hardware/3D-Objekte Dateien/Transparente Objekte/Heizung.stl
8.00 x 50.0 x 35.0

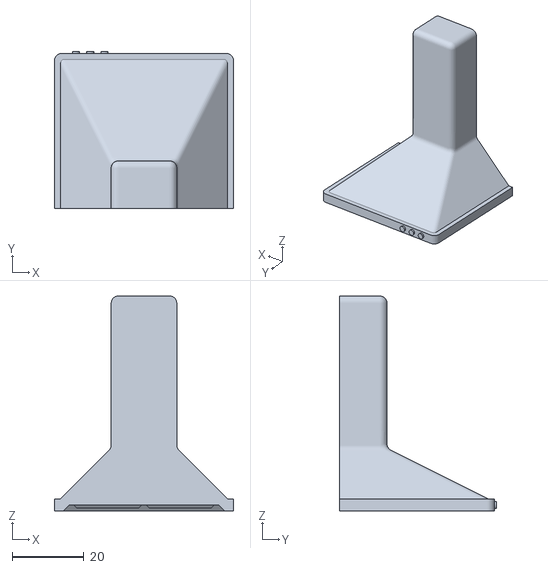
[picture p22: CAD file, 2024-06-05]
docu/hardware/3D-Objekte Dateien/Weitere Objekte/Küche/Verdunstungshaube.stl
50.0 x 43.9 x 60.0

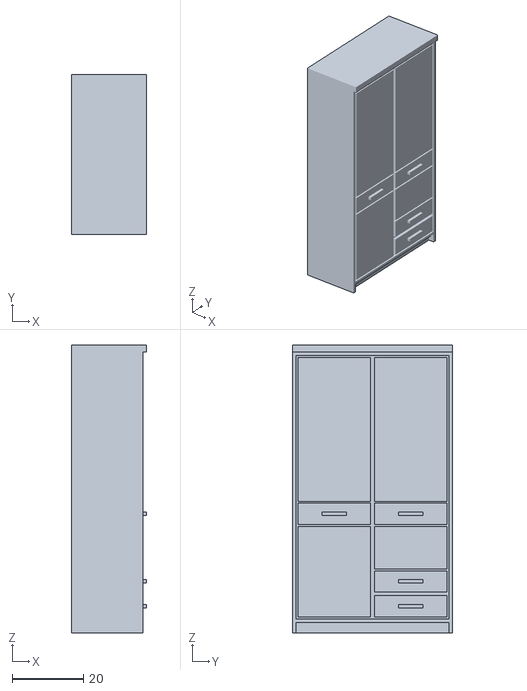
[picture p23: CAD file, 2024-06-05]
docu/hardware/3D-Objekte Dateien/Weitere Objekte/Schlafzimmer/Kleiderschrank.stl
21.0 x 45.0 x 81.0

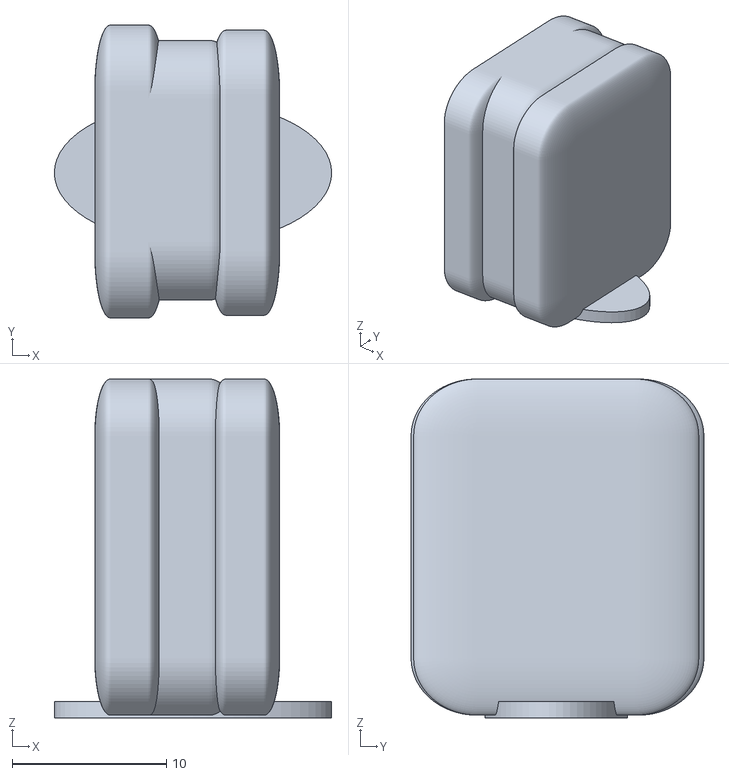
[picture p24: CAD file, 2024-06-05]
docu/hardware/3D-Objekte Dateien/Weitere Objekte/Wohnzimmer/Spielkonsole.stl
18.0 x 19.0 x 22.0

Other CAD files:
docu/hardware/3D-Objekte Dateien/Transparente Objekte/Lampe.stl
docu/hardware/3D-Objekte Dateien/Weitere Objekte/Küche/Küchenschranktüre.stl
docu/hardware/3D-Objekte Dateien/Weitere Objekte/Schlafzimmer/Nachttisch.stl
docu/hardware/3D-Objekte Dateien/Weitere Objekte/Küche/Küche_Waschbecken.stl
docu/hardware/3D-Objekte Dateien/Weitere Objekte/Küche/Küchenschrank.stl
docu/hardware/3D-Objekte Dateien/Weitere Objekte/Schlafzimmer/Bürotisch.stl
docu/hardware/3D-Objekte Dateien/Weitere Objekte/Wohnzimmer/Aquarium_Deckel.stl
docu/hardware/3D-Objekte Dateien/Weitere Objekte/Wohnzimmer/Aquarium_Rahmen.stl
docu/hardware/3D-Objekte Dateien/Weitere Objekte/Wohnzimmer/Bücherregal.stl
docu/hardware/3D-Objekte Dateien/Weitere Objekte/Wohnzimmer/Fernsehtisch.stl
docu/hardware/3D-Objekte Dateien/Weitere Objekte/Wohnzimmer/Sofa.stl

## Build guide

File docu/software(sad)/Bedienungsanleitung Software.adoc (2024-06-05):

= Bedienungsanleitung für die Spielsoftware

== Software (Spiel)

=== Spielübersicht

*Ziel des Spiels*

Unser Produkt ist ein physisches Spiel, welches auf spielerische Art Jugendlichen aufzeigt. Wie der Umgang mit Energiesparen effizient gestaltet werden kann.
Das Spiel findet in einem physischen Puppenhaus statt und handelt um das Energiemonster Elektronix,
welches traurig ist, da dieser keine Energie mehr hat. Der spielenden Person werden verschiedene Aufgaben gestellt,
indem im Haus Alltagsgegenstände ein- oder ausgeschaltet werden müssen. Diese Gegenstände sind jeweils mit LEDs
versehen und werden mithilfe eines Druckknopfes eingeschaltet. Das Ziel ist es, Energie im Haus zu sparen, indem je nach
der Situation, dass Gegenstände ein- und ausgeschaltet werden und Elektronix sich mit dieser Energie aufladen kann und somit zufrieden ist.

*Hauptfeatures*

[cols="1,2,6", options="header"]
|===
| ID
| Name
| Kurzbeschreibung

| F01
| Spielführung (Gameplay)
| Spieler*innen interagieren mit dem Puppenhaus, steuern verschiedene Alltagsgegenstände und erleben ein unterhaltsames sowie lehrreiches Gameplay. Die Spielführung leitet die Nutzer durch Szenarien, in denen sie ihre Entscheidungen bezüglich des Energieverbrauchs treffen.

| F02
| Interaktion UI-Spielmenü (Druckknöpfe, Display)
| Das Display des Spielmenüs bietet eine benutzerfreundliche Oberfläche, über die Spieler*innen das Spiel starten und Informationen über ihre Fortschritte erhalten können. Die intuitive Navigation ermöglicht eine reibungslose Interaktion.

| F03
| Energieverbrauchssimulation von Alltagsgegenständen
| Spieler*innen erleben eine realistische Simulation, bei der sie den Energieverbrauch von Alltagsgegenständen im Puppenhaus steuern. Die Interaktion vermittelt ein Verständnis für die Auswirkungen von Entscheidungen auf den Energieverbrauch.

| F04
| Portability und Usability
| Das Spiel oder Exponat soll leicht transportierbar sein. Die schnelle Auf- und Abbauzeit gewährleistet eine effiziente Nutzung, während die Sicherheit und einfache Handhabung für den Betreiber ein essentielles Bedürfnis ist. Die Selbsterklärung des Spieles und eine schnelle Antwortzeit sind entscheidend, um das Interesse der Schüler*innen im primären Zielpublikum (7. - 9. Schuljahr) zu erhalten.

| F05
| Szenarien mit Entscheidungsmöglichkeiten
| Spieler*innen interagieren mit realistischen Alltagsszenarien im Puppenhaus, treffen Entscheidungen zur Energieeffizienz und erleben unmittelbare Auswirkungen auf den Spielfortschritt. Diese Szenarien fördern ein spielerisches Verständnis für nachhaltige Entscheidungsprozesse.

| F06
| Anzeige von Statistiken und Feedback
| Spieler*innen erhalten Statistik über ihren Energieverbrauch und Feedback zu ihren Entscheidungen. Dies ermöglicht eine selbstreflektierte Analyse und fördert das Verständnis für energieeffizientes Verhalten.

|===

'''

=== Neuinstallation

*Vorbereitung:*
Vor der Neuinstallation sollten alle wichtigen Daten gesichert werden. Es ist empfehlenswert, dass die aktuelle Version des Spiels deinstalliert wird, um mögliche Konflikte mit der neuen Installation zu vermeiden.

==== Setup Raspberry Pi 4

**Raspberry Pi OS Installation**
Zur Neuinstallation eines Raspberry Pis muss zuerst das richtige OS installiert werden. Folgen Sie dazu dem https://www.pi4j.com/getting-started/set-up-a-new-raspberry-pi/[Pi4J Setup Guide].

**Remote-Verbindung zum Raspberry Pi**
Nach der OS Installation muss eine Maus, Tastatur und ein Monitor am RasPi angeschlossen werden. Für die Verbindung mit Ihrem Computer befolgen Sie folgende Schritte:

RasPi mit Strom versorgen. Der RasPi startet automatisch und bootet in das OS.

RaspberryPi mit einem Netzwerk verbinden. (Netzwerkassistent des OS nutzen)

Nach dem erfolgreichen Verbinden mit einem Netzwerk wird die IP-Adresse im Desktop-Hintergrundbild angezeigt.

Nun kann mit der Run Konfiguration "Run on PI(X11)" welche von Maven importiert wird, wenn das POM als Maven Projekt geladen wird, ausgeführt werden.

falls die Verbindung fehlschlägt, überprüfen Sie, ob sich der PC im gleichen LAN wie der Raspberry Pi befindet.

Zur Problemlösung und weiteren Informationen verweisen wir auf:

https://www.pi4j.com/[Pi4J Projekt - Homepage]

https://www.raspberrypi.com/documentation/[Raspberry Pi - Dokumentation]

===== Run on Pi (X11)
Mit dem Ausführen der "Run on Pi(X11)"-Run Konfiguration werden alle für die Applikation benötigten Artifakte auf das RasPi in den "/home/pi/deploy"-Ordner kopiert. Zudem werden Skripts für die Installation des Autostarts der Applikation in diesen Ordner kopiert. All diese Artifakte sind in der "POM.xml"-Datei deklariert.

===== Einrichten des Raspberry Pi
Für das Einrichten des Raspberry Pi’s werden mehrere Skripts benötigt. Diese werden bei jedem Deployment auf den Raspberry Pi kopiert. Diese Skripts sind unter anderem dazu da, die Monitor Einstellungen zu übernehmen und den Autostart des Spiels einzurichten.

Dazu existiert eine Run-Konfiguration "Installscript on Pi" welche die Scripts auf dem Raspberry Pi ausführen und alles einrichten.

'''
=== Spielsteuerung
* Steuerungselemente
* Anpassung der Steuerungseinstellungen

Dieser Abschnitt erläutert die Interaktionsmechanismen und Konfigurationsmöglichkeiten der Spielsteuerung, die darauf ausgelegt sind, eine intuitive und anpassbare Benutzererfahrung zu ermöglichen.

*1. Steuerungselemente:*

Das zentrale Interface für die Spielinteraktion befindet sich auf einem Schaltpult, das alle notwendigen Steuerungselemente umfasst:

*Druckknöpfe:*
Über diese Knöpfe steuern die Spieler*innen die Ein- und Ausschaltung von Genständen im Puppenhaus, was direkte Auswirkungen auf den Energieverbrauch hat.

*Display:*
Das Display am Schaltpult ist zentral für die Interaktion der Spieler mit dem Spiel. Es bietet  Informationen und visuelles Feedback zu den Spielaktionen und -ergebnissen:

* Das Display zeigt Fragen zum Energiesparen und gibt Tipps. Diese können darauf hinweisen, ob eine Aktion richtig oder falsch war, um den Spielern zu helfen, energieeffizientere Entscheidungen zu treffen.

* Die Anzahl der Punkte, die die Spieler basierend auf ihren Aktionen und Entscheidungen im Spiel sammeln, werden deutlich mit einem Barometer dargestellt.

* Die Stimmung des Elektronix, der je nach den Aktionen der Spieler glücklich oder traurig sein kann, wird visuell auf dem Display angezeigt.

*2. Anpassung der Steuerungseinstellungen:*

Dieser Abschnitt erläutert, wie die Steuerungselemente im Code angepasst werden können, falls Anpassungen nötig sind. Das bezieht sich auf die Funktionalitäten der Druckknöpfe und das Display, welche zentral für die Interaktion im Spiel sind.

*Anpassung der Druckknöpfe:* Die Druckknöpfe werden durch die Klasse *SimpleButton* im Paket (com.pi4j.mvc.powerhouse.components) gesteuert. Diese Klasse ist für die Behandlung der Eingaben von Druckknöpfen zuständig und bietet Methoden, um auf verschiedene Zustände der Druckknöpfe zu reagieren. Jede Methode enthält kurze Kommentare, die deren Zweck beschreiben.

*Anpassung des Displays:* Im Projektverzeichnis wird der Ordner *view* gefunden, der in *gui* und *pui* unterteilt ist und beim *resources* wird den *questions.json* gefunden. Diese Bereiche sind für die Steuerung der Logik und des Layouts der Benutzeroberfläche zuständig.

*ioAll.csv:* Dieses CSV befindet sich im Paket (com.pi4j.mvc.powerhouse.components). Hier können die LEDs und Druckknöpfe einander zugeordnet werden. "E + Zahl" sind für die LEDs und "D + Zahl" sind für die Buttons. Die folgende Tabelle kennzeichnet jedem Simulationsgegenstand im Puppenhaus eine PIN-Nummer (Ex oder Dx), welches dem Gegenstand jeweils ein Button und eine LED zuweist. Auf Grund den technischen Gegebenheiten des Raspberry Pi 4 bezüglich GPIO-Pins, ist das Spiel auf zwei zusätzliche I2C Output Extension-Boards angewiesen, dass die entsprechenden LEDs separat anschließt und ansteuert. *Simulations-Gegenstände müssen exakt mit der Bezeichnung im 'questions.json' (Attribute: "activeAtStart" & "Answer") übereinstimmen.*

[cols="2,2,2,1,1" , options="header"]
|===
|Raum im Puppenhaus
|Simulations-Gegenstand
|Device-Adresse des I2C Extension-Board
|LED-PIN
|Button-PIN
.4+|Schlafzimmer| LampeSchlafzimmer      | 32  | E1  | D4
                | NachttischLampe        | 32  | E3  | D6
                | Heizung                | 32  | E4  | D11
                | Computer               | 32  | E6  | D5
.2+|Badezimmer  | LampeBadezimmer        | 32  | E5  | D16
                | Waschmaschine/Tumbler  | 32  | E2  | D17
.3+|Wohnzimmer  | LampeWohnzimmer        | 34  | E6  | D20
                | Fernseher/Spielkonsole | 34  | E3  | D25
                | Aquarium               | 34  | E4  | D23
.3+|Küche       | LampeKueche            | 34  | E1  | D22
                | Herd/Backofen          | 34  | E2  | D21
                | Kuehlschrank           | 34  | E5  | D24
|===

==== questions.jason
Diese JSON-Datei enthält die Definitionen der Fragen und ist zentral für die Anpassung der Spielinhalte. Durch Änderungen an dieser Datei können die Fragen und Antworten, die im Spiel verwendet werden, modifiziert oder erweitert werden. Jede Frage benötigt Folgendes:

* *Difficulty:* Hier wird der Schwierigkeitsgrad einer Frage bestummen. Es gibt:
   - Einstiegslevel: Hier können keine Punkte gewonnen oder verloren werden.
   - Easy: 10 Punkte gewinnen oder 5 Punkte verlieren
   - Medium: 20 Punkte gewinnen oder 10 Punkte verlieren
   - Hard: 30 Punkte gewinnen oder 15 Punkte verlieren

Die Difficulty kann im Enum "Difficulty" im Paket "Game"  angepasst werden.

* *Question:* Hier wird die Aufgabe gestellt.
* *ActiveAtStart:* Hier werden die Gegenstände aufgelistet, die zu Beginn des Levels an sein sollten. (Gegenstände müssen exakt mit der Bezeichnung im 'ioAll.csv' übereinstimmen.)
* *Answer:* In Answer wird festgelegt, welche Gegenstände nach der gelösten Aufgabe noch an sein sollten.
* *WinMessage:* In der WinMessage wird die Nachricht eingefügt, wenn die Aufgabe richtig gelöst wurde.
* *FailMessage:* In der FailMessage wird die Nachricht eingefügt, wenn die Aufgabe richtig gelöst wurde.
* *ImagePath:* Hier wird der Path zum Bild von Elektronix eingefügt werden.
* *ImagePathWeather:* Hier wird der Path zum Bild vom Wetter eingefügt.

'''
=== Wartung
Die regelmässige Wartung der Software des Puppenhausspiels ist entscheidend, um Stabilität, Sicherheit und optimale Leistung zu gewährleisten. Folgende Punkte sind dabei besonders wichtig:

*Aktualisierung der Software:* Für die Aktualisierung der Software muss man den Maven-Build ausführen.

*Löschen der alten Installation:* Möchte die alte Installation gelöscht werden, muss der Deply-Folder gelöscht werden.

'''

=== Werkzeuge
* Werkzeuge die gebraucht werden, wenn am Haus was angepasst wird.

Für die Installation, Wartung und Anpassung der Spielsoftware sind verschiedene Werkzeuge erforderlich, die sowohl die Softwareprogrammierung als auch die Hardwarekonfiguration umfassen. Folgende Werkzeuge werden verwendet:

*Software-Entwicklungswerkzeuge:*

[cols="1,2,6"]
|===
| Programmiersprache:
| Java
| Verwendung für die Kernentwicklung der Spiellogik und Interaktionen.

| Frontend Stack:
| JavaFX und CSS
| • JavaFX wird verwendet, um eine benutzerfreundliche Oberfläche zu gestalten, die auf einem Raspberry Pi funktioniert.

• CSS wird zur Gestaltung der Benutzeroberfläche genutzt, um das Spiel visuell ansprechend zu machen.
|===

*Hardware-Entwicklungswerkzeuge:*

[cols="1,2,6"]
|===
|Backend Stack:
|Pi4J
|Pi4J ermöglicht die Interaktion zwischen der Java Anwendung und der GPIO-Schnittstelle des Raspberry Pi. Dies wird genutzt, um Sensoren und Aktoren im Puppenhaus zu steuern.

|Plattform für die Implementierung:
|Raspberry Pi
|Dient als zentrale Steuereinheit für das Puppenhaus, auf der die Spielsoftware läuft und die Hardwarekomponenten gesteuert werden.
|===

*Hinweise zur Verwendung der Werkzeuge:*
Es ist wichtig, dass Entwickler und Techniker, die mit diesen Werkzeugen arbeiten, entsprechende Kenntnisse in der Java-Programmierung und Erfahrung im Umgang mit Raspberry Pi haben.

'''

=== Fehlerbehebung
*Shellskript funktioniert nicht Ordnungsgemäss?*

Eine häufige Fehlerquelle im Zusammenhang mit Shellskripten ist, dass die Linebreaks im Shellskript falsch formatiert sind. Dies kann auftreten, wenn die Shellskripts in einer IDE über einen Windowscomputer deployed wurden.
→ Stellen Sie sicher, dass die Linebreaks in der IDE auf 'LF', also für Unix und MacOS eingestellt sind. (LF Linebreaks: "\n")
Hardware

*Wechseln von Hardware Komponenten*

* Button: Die Buttons sind mit dem Brett verschraubt. Zuerst muss die Buttonkappe entfernt werden. Diese ist mit einem Doppelseitigenklebeband befestigt. Anschliessend kann die Mutter um den Knopf gelöst werden und nach hinten herausgedrückt werden.
* LEDs: Falls eine LED gewechselt werden muss. Die Plexiglasscheibe kan vom Haus ganz einfach entfernt werden, da diese nur mit zwei Klettverschlüssen und Magneten befestigt ist. Die LEDs sind mit Heissleim befestigt. Der Leim muss zuerst erhitzt werden und kann anschliessend weggenommen werden.
* Möbel: Möchte man ein Möbel ersetzen, kann die Plexiglasscheibe vom Haus entfernt werden. Die Möbel sind alle ebenfalls mit Heisleim befestigt. Auch hier muss der Leim zuerst erhizt werden, damit die Möbel entfert werden können.

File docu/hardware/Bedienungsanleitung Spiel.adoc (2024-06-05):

= Spielanleitung

== Einleitung und Ziel des Spiels

Im Spiel "Powerhouse" begleitet das Energiemonster Elektronix die Spieler*innen durch alle Levels.
Elektronix fühlt sich leider traurig, da im Haus zu viel Energie verschwendet wird.
Deshalb ist das Ziel des Spiels, die Stimmung von Elektronix zu verbessern, indem im Haus effizient Energie gespart wird.

Das Spiel besteht aus drei Schwierigkeitsgraden: einfach, mittel und schwer. Jede Schwierigkeit entspricht einem Tag.
Das Spiel findet ausschliesslich im Haus statt, um die Szenarien im echten Leben widerzuspiegeln und damit die Spieler*innen dies auch in ihrem Alltag umsetzen können. Es soll die Wichtigkeit des Umgangs mit Strom und Energie aufzeigen.

== Spielstart

Das Spiel startet mit einem Startbildschirm, der den Titel "Powerhouse" und Elektronix zeigt.
Zu Beginn wird ein kurzes Szenario präsentiert, in dem Elektronix seine Situation erklärt: Er ist traurig und hat kaum Energie,
weil im Haus zu viel Energie verschwendet wird.
Diese Einführung soll die Spieler*innen emotional mit Elektronix verbinden und die Bedeutung des Energiesparens verdeutlichen.

Die erste Aufgabe dient als Testaufgabe, bei der die Spieler*innen alle Lampen einschalten sollen. Diese Handlung hilft
nicht nur dabei, das grundlegende Ziel des Spiels – Energie zu sparen – zu verstehen, sondern gibt auch Elektronix die nötige
Energie, was sofortiges positives Feedback erzeugt. Parallel dazu wird eine interaktive Anleitung zur Steuerung eingeführt.
Spieler*innen lernen, wie sie das Schaltpult mit physischen Druckknöpfen und LED-Anzeigen für jedes Zimmer nutzen können.

Gleichzeitig wird das Energiebarometer eingeführt, das anzeigt, wie viel Energie bereits gespart wurde, beginnend bei 0 Punkten.
Das Barometer steigt bei jeder Aufgabe, die richtig gelöst wurde und sinkt, bei jeder falsch gelösten Aufgabe.

Nach erfolgreichem Abschluss der Testaufgabe und dem Kennenlernen der Steuerung beginnt das Spiel offiziell. Es folgen weitere Levels mit zunehmender Schwierigkeit, bei denen die Spieler*innen aufgefordert werden, in verschiedenen Szenarien des Haushalts strategisch Energie zu sparen.

=== Erklärung der Benutzeroberfläche und Steuerung

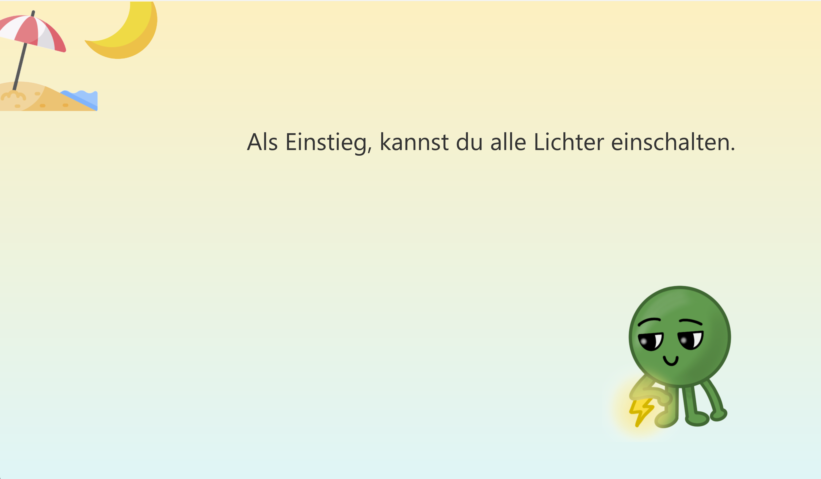
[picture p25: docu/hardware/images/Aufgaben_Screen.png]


Auf dem Bildschirm erscheinen die Fragen mit der jeweiligen Jahreszeit und Tageszeit (Sommer, Winter, Tag und Nacht). Nach fast jedem Level ändern sich diese Zeiten. Sie werden als Icon in der linken oberen Ecke dargestellt.
Da jede Schwierigkeit einen Tag darstellt, wird auch nach jedem Tag eine neue Jahreszeit eingeführt (Sommer, Winter und wieder Sommer).

Für jedes Level wird auch ein Bild von Elektronix angezeigt, sodass die Spieler*innen visuell sehen können, wie sich Elektronix fühlt und welches Thema das Level hat.

Zudem wird auch angezeigt, ob eine Aufgabe richtig oder falsch gelöst wurde. Bei falschen Antworten erhält der/die Spieler*in die Lösung.
Am Ende des Spiels haben die Spieler*innen die Möglichkeit, das Spiel zu wiederholen.
Ein Energiebalken zeigt auch an, wie viel Energie gespart wurde. Bei einer richtigen Antwort steigt der Energiebalken, da Energie gespart wurde, während er bei einer falschen Antwort sinkt, da Energie verbraucht wurde.

Es gibt eine Möglichkeit, das Spiel jederzeit abzubrechen, weshalb bei einem Abbruch Elektronix gezeigt wird und das erreichte Energieersparnis.

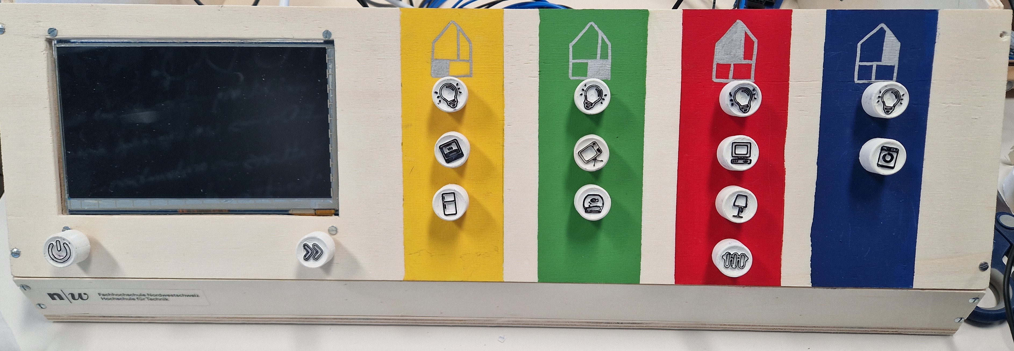
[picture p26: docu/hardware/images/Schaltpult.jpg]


Am Schaltpult sind 14 Knöpfe für alle Räume zu sehen, die mit einer grünen LED versehen sind. Mit diesen Knöpfen können Gegenstände ein- und ausgeschaltet werden, wobei diese entsprechend im Haus aufleuchten.
Zudem gibt es noch einen "Weiter"-Knopf, der gedrückt werden kann, wenn eine Aufgabe fertig gelesen oder ausgeführt wurde.
Der "Abbruch"-Knopf dient dazu, das Spiel zu beenden, falls die spielende Person nicht mehr spielen möchte.

Liste der Knöpfe und Räume von links nach rechts:
[cols="1,1" options="header"]
|===
|Raum |Gegenstände
|Küche (gelb) |Lampe, Fernseher/Spielkonsole, Aquarium
|Wohnzimmer (grün) |Lampe, Herd/Backofen, Kühlschrank
|Schlafzimmer (rot) |Lampe, Nachttischlampe, Computer, Heizung
|Badezimmer (blau) |Lampe, Waschmaschine/Trockner
|===

Jeder Knopf steuert ein spezifisches elektrisches Gerät im Haus. Das Ein- und Ausschalten dieser Geräte beeinflusst den
Energieverbrauch und damit die Punktzahl des Spielers.

Am Ende jedes Levels wird den Spielern die Wahl gelassen, ob sie mit dem nächsten Level fortfahren oder das Spiel beenden
möchten. Durch Betätigen des "Weiter"-Knopfs gelangt der Spieler zum nächsten Level, während der "Abbruch"-Knopf es ermöglicht, das Spiel jederzeit zu beenden und bei Bedarf neu zu starten.

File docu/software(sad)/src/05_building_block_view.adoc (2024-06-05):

[[section-building-block-view]]
== Bausteinsicht

[role="arc42help"]
****
.Inhalt
Die Bausteinsicht zeigt die statische Zerlegung des Systems in Bausteine (Module, Komponenten, Subsysteme, Klassen, Schnittstellen, Pakete, Bibliotheken, Frameworks, Schichten, Partitionen, Tiers, Funktionen, Makros, Operationen, Datenstrukturen, ...) sowie deren Abhängigkeiten (Beziehungen, Assoziationen, ...)

Diese Sicht sollte in jeder Architekturdokumentation vorhanden sein.
In der Analogie zum Hausbau bildet die Bausteinsicht den _Grundrissplan_.

.Motivation
Behalten Sie den Überblick über den Quellcode, indem Sie die statische Struktur des Systems durch Abstraktion verständlich machen.

Damit ermöglichen Sie Kommunikation auf abstrakterer Ebene, ohne zu viele Implementierungsdetails offenlegen zu müssen.

.Form
Die Bausteinsicht ist eine hierarchische Sammlung von Blackboxen und Whiteboxen (siehe Abbildung unten) und deren Beschreibungen.

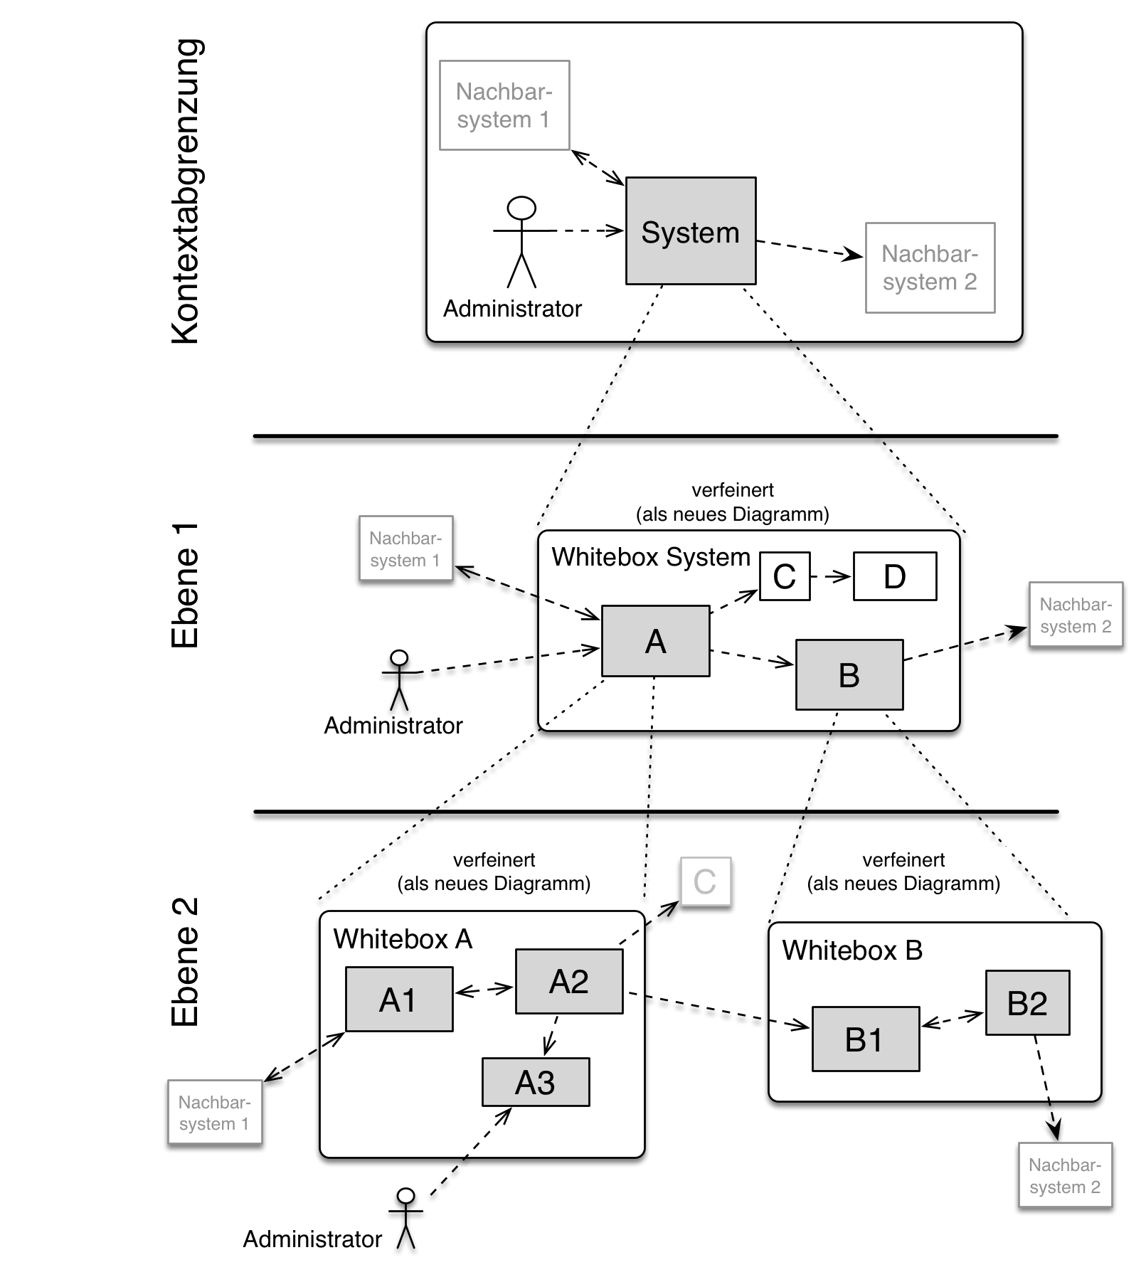
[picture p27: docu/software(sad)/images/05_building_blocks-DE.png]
Hierarchie in der Bausteinsicht


*Ebene 1* ist die Whitebox-Beschreibung des Gesamtsystems, zusammen mit Blackbox-Beschreibungen der darin enthaltenen Bausteine.

*Ebene 2* zoomt in einige Bausteine der Ebene 1 hinein.
Sie enthält somit die Whitebox-Beschreibungen ausgewählter Bausteine der Ebene 1, jeweils zusammen mit Blackbox-Beschreibungen darin enthaltener Bausteine.

*Ebene 3* zoomt in einige Bausteine der Ebene 2 hinein, usw.

.Weiterführende Informationen

Siehe https://docs.arc42.org/section-5/[Bausteinsicht] in der online-Dokumentation (auf Englisch!).
****

=== Whitebox Gesamtsystem

[role="arc42help"]
****
An dieser Stelle beschreiben Sie die Zerlegung des Gesamtsystems anhand des nachfolgenden Whitebox-Templates.
Dieses enthält:

* Ein Übersichtsdiagramm
* die Begründung dieser Zerlegung
* Blackbox-Beschreibungen der hier enthaltenen Bausteine.
Dafür haben Sie verschiedene Optionen:

** in _einer_ Tabelle, gibt einen kurzen und pragmatischen Überblick über die enthaltenen Bausteine sowie deren Schnittstellen.
** als Liste von Blackbox-Beschreibungen der Bausteine, gemäß dem Blackbox-Template (siehe unten).
Diese Liste können Sie, je nach Werkzeug, etwa in Form von Unterkapiteln (Text), Unter-Seiten (Wiki) oder geschachtelten Elementen (Modellierungswerkzeug) darstellen.

* (optional:) wichtige Schnittstellen, die nicht bereits im Blackbox-Template eines der Bausteine erläutert werden, aber für das Verständnis der Whitebox von zentraler Bedeutung sind.
Aufgrund der vielfältigen Möglichkeiten oder Ausprägungen von Schnittstellen geben wir hierzu kein weiteres Template vor.
Im schlimmsten Fall müssen Sie Syntax, Semantik, Protokolle, Fehlerverhalten, Restriktionen, Versionen, Qualitätseigenschaften, notwendige Kompatibilitäten und vieles mehr spezifizieren oder beschreiben.
Im besten Fall kommen Sie mit Beispielen oder einfachen Signaturen zurecht.
****

_**<Übersichtsdiagramm>**_

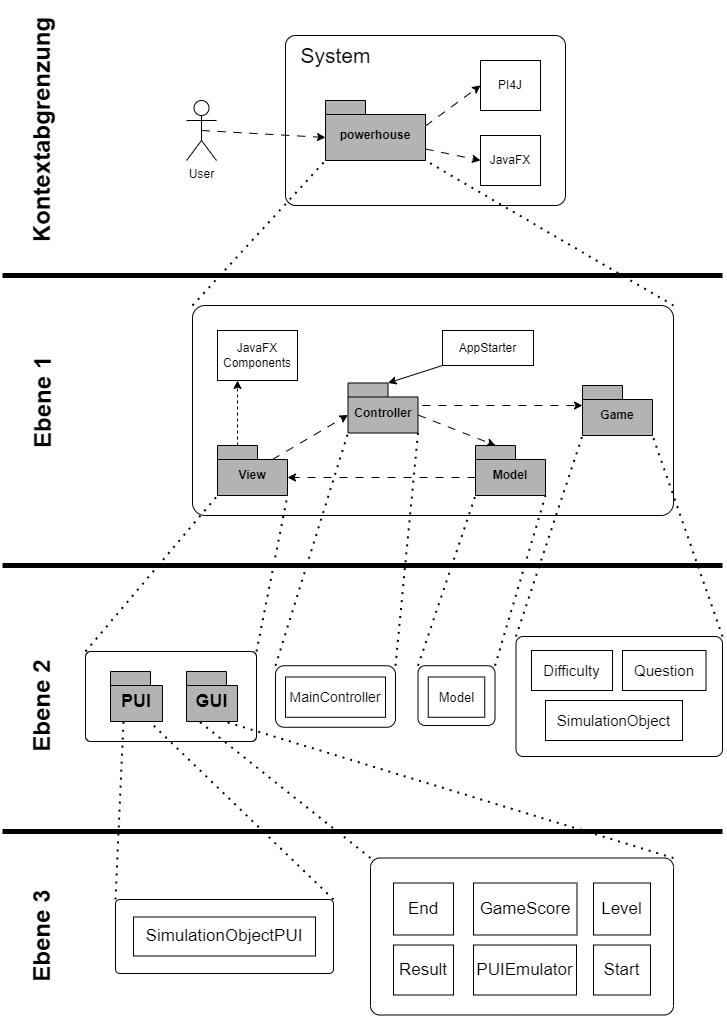
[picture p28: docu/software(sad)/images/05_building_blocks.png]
Bild: Bausteinansicht Powerhouse


Begründung::
Die Zerlegung erfolgt nach dem Model-View-Controller Muster. Dieses Muster erlaubt uns eine unabhängige Entwicklung und eine übersichtliche Architektur.

Enthaltene Bausteine:: _<Beschreibung der enthaltenen Bausteine (Blackboxen)>_

[cols="1,2" options="header"]
|===
| Name | Verantwortung
| Model | Speicherung der Zustände
| View | Anzeige des GUI und der PUI
| Controller | Änderung und Logik der Komponenten
|===

Wichtige Schnittstellen:: _<Beschreibung wichtiger Schnittstellen>_

[role="arc42help"]
****
Hier folgen jetzt Erläuterungen zu Blackboxen der Ebene 1.

Falls Sie die tabellarische Beschreibung wählen, so werden Blackboxen darin nur mit Name und Verantwortung nach folgendem Muster beschrieben:

[cols="1,2" options="header"]
|===
| **Name** | **Verantwortung**
| _<Blackbox 1>_ | _<Text>_
| _<Blackbox 2>_ | _<Text>_
|===

Falls Sie die ausführliche Liste von Blackbox-Beschreibungen wählen, beschreiben Sie jede wichtige Blackbox in einem eigenen Blackbox-Template.
Dessen Überschrift ist jeweils der Namen dieser Blackbox.
****

==== <Name Blackbox 1>

[role="arc42help"]
****
Beschreiben Sie die <Blackbox 1> anhand des folgenden Blackbox-Templates:

* Zweck/Verantwortung
* Schnittstelle(n), sofern diese nicht als eigenständige Beschreibungen herausgezogen sind.
Hierzu gehören eventuell auch Qualitäts- und Leistungsmerkmale dieser Schnittstelle.
* (Optional) Qualitäts-/Leistungsmerkmale der Blackbox, beispielsweise Verfügbarkeit, Laufzeitverhalten o. Ä.
* (Optional) Ablageort/Datei(en)
* (Optional) Erfüllte Anforderungen, falls Sie Traceability zu Anforderungen benötigen.
* (Optional) Offene Punkte/Probleme/Risiken
****

_<Zweck/Verantwortung>_

_<Schnittstelle(n)>_

_<(Optional) Qualitäts-/Leistungsmerkmale>_

_<(Optional) Ablageort/Datei(en)>_

_<(Optional) Erfüllte Anforderungen>_

_<(optional) Offene Punkte/Probleme/Risiken>_

==== <Name Blackbox 2>

_<Blackbox-Template>_

==== <Name Blackbox n>

_<Blackbox-Template>_

==== <Name Schnittstelle 1>

...

==== <Name Schnittstelle m>

=== Ebene 2

[role="arc42help"]
****
Beschreiben Sie den inneren Aufbau (einiger) Bausteine aus Ebene 1 als Whitebox.

Welche Bausteine Ihres Systems Sie hier beschreiben, müssen Sie selbst entscheiden.
Bitte stellen Sie dabei Relevanz vor Vollständigkeit.
Skizzieren Sie wichtige, überraschende, riskante, komplexe oder besonders volatile Bausteine.
Normale, einfache oder standardisierte Teile sollten Sie weglassen.
****

==== Whitebox _<Baustein 1>_

[role="arc42help"]
****
...zeigt das Innenleben von _Baustein 1_.
****

_<Whitebox-Template>_

==== Whitebox _<Baustein 2>_

_<Whitebox-Template>_

...

==== Whitebox _<Baustein m>_

_<Whitebox-Template>_

=== Ebene 3

[role="arc42help"]
****
Beschreiben Sie den inneren Aufbau (einiger) Bausteine aus Ebene 2 als Whitebox.

Bei tieferen Gliederungen der Architektur kopieren Sie diesen Teil von arc42 für die weiteren Ebenen.
****

==== Whitebox <_Baustein x.1_>

[role="arc42help"]
****
...zeigt das Innenleben von _Baustein x.1_.
****

_<Whitebox-Template>_

==== Whitebox <_Baustein x.2_>

_<Whitebox-Template>_

==== Whitebox <_Baustein y.1_>

_<Whitebox-Template>_

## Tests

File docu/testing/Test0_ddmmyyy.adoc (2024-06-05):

//== Test 0

//[%autowidth]
//|===
//|Datum | dd.mm.yyy
//|Verantwortlich | Max Muster
//|===

//include::TestCases/1_1_EinAusschalten.adoc[]

//*Status:* Erfolgreich

//*Bemerkungen:* Der Knopf lies sich nur schwer drücken.

== Test1:
|===
|Datum | dd.mm.yyy
|Verantwortlich | David - Ali
|Test ID |
|Testtitel|
|Beschreibung|
|Annahmen und Voraussetzungen|
|Testdaten|
|Auszuführende Schritte|
|Erwartetes Ergebnis|
|Status|
|Bemerkungen|
|===

== Test2:
|===
|Datum | dd.mm.yyy
|Verantwortlich | David - Ali
|Test ID |
|Testtitel|
|Beschreibung|
|Annahmen und Voraussetzungen|
|Testdaten|
|Auszuführende Schritte|
|Erwartetes Ergebnis|
|Status|
|Bemerkungen|
|===

== Test3:
|===
|Datum | dd.mm.yyy
|Verantwortlich | David - Ali
|Test ID |
|Testtitel|
|Beschreibung|
|Annahmen und Voraussetzungen|
|Testdaten|
|Auszuführende Schritte|
|Erwartetes Ergebnis|
|Status|
|Bemerkungen|
|===

== Test4:
|===
|Datum | dd.mm.yyy
|Verantwortlich | David - Ali
|Test ID |
|Testtitel|
|Beschreibung|
|Annahmen und Voraussetzungen|
|Testdaten|
|Auszuführende Schritte|
|Erwartetes Ergebnis|
|Status|
|Bemerkungen|
|===

== Test5:
|===
|Datum | dd.mm.yyy
|Verantwortlich | David - Ali
|Test ID |
|Testtitel|
|Beschreibung|
|Annahmen und Voraussetzungen|
|Testdaten|
|Auszuführende Schritte|
|Erwartetes Ergebnis|
|Status|
|Bemerkungen|
|===

== Test6:
|===
|Datum | dd.mm.yyy
|Verantwortlich | David - Ali
|Test ID |
|Testtitel|
|Beschreibung|
|Annahmen und Voraussetzungen|
|Testdaten|
|Auszuführende Schritte|
|Erwartetes Ergebnis|
|Status|
|Bemerkungen|
|===

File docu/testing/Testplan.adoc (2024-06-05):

= Testplan

// https://de.parasoft.com/blog/how-to-write-test-cases-for-software-examples-tutorial/
// Beschreiben Sie hier, wann Sie was testen wollen.

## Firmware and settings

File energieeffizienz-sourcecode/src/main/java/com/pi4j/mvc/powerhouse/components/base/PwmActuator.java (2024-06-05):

package com.pi4j.mvc.powerhouse.components.base;

import com.pi4j.context.Context;
import com.pi4j.io.pwm.Pwm;
import com.pi4j.io.pwm.PwmConfig;
import com.pi4j.plugin.mock.provider.pwm.MockPwm;

import java.util.List;

public class PwmActuator extends Component {
    protected static final List<PIN> AVAILABLE_PWM_PINS = List.of(PIN.PWM12, PIN.PWM13, PIN.PWM18, PIN.PWM19);

    protected final Pwm pwm;

    protected PwmActuator(Context pi4J, PwmConfig config) {
        if(AVAILABLE_PWM_PINS.stream().noneMatch(p -> p.getPin() == config.address())){
            throw new IllegalArgumentException("Pin " + config.address() + " is not a PWM Pin");
        }
        pwm = pi4J.create(config);
    }

    @Override
    public void reset() {
        pwm.off();
    }

    // --------------- for testing --------------------

    public MockPwm mock() {
        return asMock(MockPwm.class, pwm);
    }
}

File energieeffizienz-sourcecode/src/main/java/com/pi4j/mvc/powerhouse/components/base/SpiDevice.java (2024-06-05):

package com.pi4j.mvc.powerhouse.components.base;

import com.pi4j.context.Context;
import com.pi4j.io.spi.Spi;
import com.pi4j.io.spi.SpiConfig;
import com.pi4j.plugin.mock.provider.spi.MockSpi;

public class SpiDevice extends Component {
    /**
     * The PI4J SPI
     */
    private final Spi spi;
    private final Context pi4j;

    protected SpiDevice(Context pi4j, SpiConfig config){
        this.pi4j = pi4j;
        spi = pi4j.create(config);
        logDebug("SPI is open");
    }

    protected void sendToSerialDevice(byte[] data) {
        spi.write(data);
    }

    @Override
    public void reset() {
        super.reset();
        spi.close();
        spi.shutdown(pi4j);
        logDebug("SPI closed");
    }

    // --------------- for testing --------------------

    public MockSpi mock() {
        return asMock(MockSpi.class, spi);
    }
}

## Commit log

2024-06-05 migrate docu and source code from gitlab
    [io.csv, ioAll.csv]
2024-06-05 add newest version of docu and fix last commit
    [Aquarium_Deckel.stl, Aquarium_Rahmen.stl, Aquarium_Tisch.stl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]
2024-06-05 links eingefügt und software anleitung korrigiert
2024-06-05 Added PIN-to-Device table for "ioAll.csv" to the "Bedienungsanleitung" file
